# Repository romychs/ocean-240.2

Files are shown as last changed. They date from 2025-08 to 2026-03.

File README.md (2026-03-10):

# Компьютер "Океан-240.2"

Схема и печатная плата новодела компьютера "Океан-240.2". Разработана на основе информации из журнала МПСС и на основе схем, чертежей, правок пользователей форума zx-pk.ru (__L Juriy__, __tnt23__, __ivagor__ и других).

## Основные характеристики

|-|-|
|---|---|
|Разрядность, бит | 8 |
|Быстродействие (рег. — рег.), операций/с| 600 000 |
|Емкость ОЗУ, К байт					 | 128/512 |
|Емкость РПЗУ, К байт					 | 16 |
|__Монитор (серийный цветной):__ | |
| в монохромном режиме |20 строк по 64 символа  |
| в цветном режиме (4 цвета) |графическое поле 256x256|
|Клавиатура | алфавитно-цифровая с контроллером на КМОП ИС | 
|__Интерфейс:__ | |
| последовательный | RS232 | 
| три параллельных программируемых канала| КР580ВВ55 |
| интерфейс печатающего устройства | ИРПР |

__Программное обеспечение:__ монитор с графическими функциями, интерпретатор Бэйсик, квазидисковая операционная система, совместимая с CP/M.

Автор ПЭВМ - __Д. А. Тилинин__

[Исходники](Sources)

[Готовые схемы](Export)

[Прошивки для микросхем ПЗУ](ROMs)

[Файлы для производства печатной платы](Gerbers/Gerber_Ocean-240.2_v1.0.3.zip)

[Темы на форуме zx.pk.ru](https://zx-pk.ru/forums/113-okean-240.html)

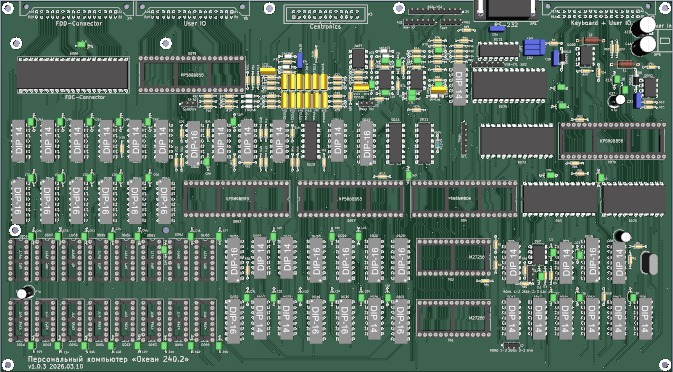
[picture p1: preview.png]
Render


## Изменения
- В версии v1.0.1, Дизассемблированы обе микросхемы ПЗУ, на основе информации из полученных исходников, немного скорректирована схема и печатная плата.
- В версии v1.0.2, Микросхемы DD5 и DD22 на схемах и шелке KiCAD, ошибочно отмечены как ЛИ1. Ошибку заметил при сборке *felix*.
- В версии v1.0.3, Исправлены ошибки предыдущей версии. Документация в папке Export и герберы сгенерированы в KiCAD. Версия EasyEDA больше не будет дорабатываться.

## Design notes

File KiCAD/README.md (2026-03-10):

# Океан-240.2 Персональный компьютер

Схема и печатная плата в [KiCAD](https://www.kicad.org/) v9.0

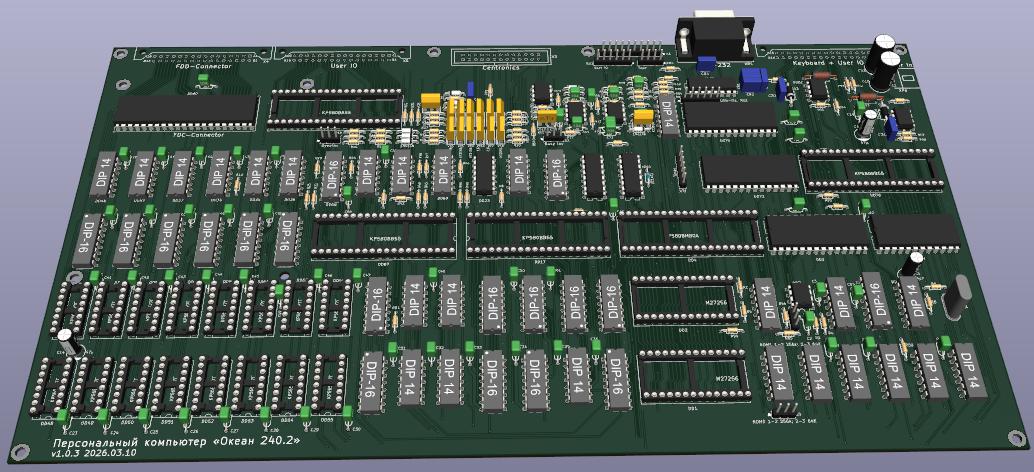
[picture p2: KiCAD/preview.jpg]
Render


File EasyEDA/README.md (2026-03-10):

# Компьютер "Океан-240.2"

Исходные файлы проекта схемы и печатной платы компьютера "Океан-240.2".

Как использовать:

В редакторе [EasyEDA](https://easyeda.com/editor), через "File" > "Open" > "EasyEDA Source", и выберите json файл и откройте его.

At editor, Click the document icon on the topbar, via "Document" > "Open" > "EasyEDA Source", and select json file, then open it at the editor.

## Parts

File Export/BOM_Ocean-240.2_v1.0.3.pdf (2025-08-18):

№ | Позиция | Название | Корпус
| | Конденсаторы
1 | C1 | 4.7μF | Электролит 5x11мм | 1
2 | C2, C3 | 160p | К10-17Б | 2
3 | C4 | 33n | К10-17Б | 1
4 | C5, C8, CR1, CR2, CR3, CR4, CR5 | 0.1μF | К10-17Б | 7
5 | C6 | 100p | К10-17Б | 1
6 | C7 | 470p | К10-17Б | 1
7 | C9, C11 | 10n | К10-17Б | 2
8 | C10 | 68n | К10-17Б | 1
9 | C12 | 2.2n | К10-17Б | 1
10 | C13, C16 | 680μF | Электролит 8x15мм | 2
11 | C14, C17 | 47μF | Электролит 5x11мм | 2
12 | C18, C20 | 1n | К10-17Б | 2
13 | C19, C21 | 1μF | К10-17Б | 2
14 | C23, C24, C25, C26, C27, C28, C29, C30, C31, C32, C33, C34, C35, C36, C37, C38, C39, C40, C41, C42, C43, C44, C45, C46, C47, C48, C50, C51, C53, C54, C55, C56, C57, C58, C60, C61, C62, C63, C64, C65, C66, C67, C68, C69, C70, C71, C72 | 1μF | К10-17Б | 47

Микросхемы
15 | DD1, DD2 | M27256 | DIP-28 | 2
16 | DD3 | КР580ВК28 | DIP-28 | 1
17 | DD4 | КР580ВМ80А | DIP-40 | 1
18 | DD5, DD22 | К1533ЛЛ1 | DIP-14 | 2
19 | DD6, DD65 | К1533ЛИ1 | DIP-14 | 2
20 | DD7 | К170АП3 | DIP-8 | 1
21 | DD8 | К1533ЛН1 | DIP-14 | 1
22 | DD9, DD16 | К1533ЛА3 | DIP-14 | 2
23 | DD10 | К1533ЛЕ1 | DIP-14 | 1
24 | DD11 | К1533ИД4 | DIP-16 | 1
25 | DD12, DD71 | К1533ТЛ2 | DIP-14 | 2
26 | DD13, DD64 | К1533ТМ2 | DIP-14 | 2
27 | DD14, DD34, DD35, DD36, DD37, DD46, DD47 | КР1533ИР16 | DIP-14 | 7
28 | DD15, DD42 | К1533ИЕ7 | DIP-16 | 2
29 | DD17, DD67, DD78, DD79, DD80 | КР580ВВ55 | DIP-40 | 5
30 | DD18, DD19, DD20 | К555ИМ6 | DIP-16 | 3
31 | DA21, DA76, DA77 | TL081 | DIP-8 | 3
32 | DD23 | К1533ЛП5 | DIP-14 | 1
33 | DD24, DD25, DD26, DD27 | К1533ИЕ5 | DIP-14 | 4
34 | DD28, DD29, DD30, DD31, DD32, DD33 | К1533КП12 | DIP-16 | 6
35 | DD38, DD39, DD40, DD41 | КР1533КП13 | DIP-16 | 4
36 | DD43 | К555СП1 | DIP-16 | 1
37 | DD44, DD45 | К1533КП11A | DIP-16 | 2
38 | DD48, DD49, DD50, DD51, DD52, DD53, DD54, DD55, DD56, DD57, DD58, DD59, DD60, DD61, DD62, DD63 | КР565РУ7Г | DIP-16 | 16
39 | DD66 | К556РТ4 | DIP-16 | 1

Коли-чество

40 | DD68, DD69 | К1533ЛН3 | DIP-14 | 2
41 | DD70 | КР580ВИ53 | DIP-24 | 1
42 | DD72 | КР580ВВ51 | DIP-28 | 1
43 | DD73 | MAX232 | DIP-16 | 1
44 | DD75 | КР580ВН59 | DIP-28 | 1
45 | DD82, DD83 | MC34063ABN | DIP-8 | 2

Индуктивности
46 | L1, L2 | 100μH | 2
| | Резисторы
47 | R1, R13, R14, R15, R31, R35, R50, R76, R80 | 5k1 | MF-0.125W | 9
48 | R2, R32, R57, R77, R78, R82, R83, R84, R94, R95, R96, R97 | 10k | MF-0.125W | 12
49 | R3, R4 | 560 | MF-0.125W | 2
50 | R5, R6, R12 | 680 | MF-0.125W | 3
51 | R8, R9, R10, R36, R61, R79, R81 | 1k5 | MF-0.125W | 7
52 | R11, R19, R20, R21 | 1k6 | MF-0.125W | 4
53 | R16, R17, R18 | 3k3 | MF-0.125W | 3
54 | R22, R23, R24, R25 | 910 | MF-0.125W | 4
55 | R26, R28, R29, R30 | 100 | MF-0.125W | 4
56 | R27 | 220 | MF-0.125W | 1
57 | R33, R67 | 20k | MF-0.125W | 2
58 | R34 | 2k | MF-0.125W | 1
59 | R37 | 10 | MF-0.125W | 1
60 | R38, R39, R40, R41, R42, R43, R44, R45, R46, R47, R48, R49, R71, R91, R92, R93 | 1k | MF-0.125W | 16
61 | R51, R52 | 0.33 | MF-0,5W | 2
62 | R53 | 82 | MF-0.125W | 1
63 | R54 | 11k | MF-0.125W | 1
64 | R55 | 1k3 | MF-0.125W | 1
65 | R58, R65, R69, R73 | 30k | MF-0.125W | 4
66 | R62, R63, R72 | 43k | MF-0.125W | 3
67 | R64 | 240k | MF-0.125W | 1
68 | R66 | 82k | MF-0.125W | 1
69 | R68, R70 | 300k | MF-0.125W | 2
70 | R74 | 1M | MF-0.125W | 1
71 | R75 | 51k | MF-0.125W | 1

Перемычки
72 | S1, S2, S3, S4 | Header 3 pin 2.54mm Male | 3

Диоды
73 | VD1, VD2, VD3, VD4, VD5, VD9, VD11, VD12 | 1N4148 | DO-35 | 8
74 | VD6, VD13 | 1N5819 | DO-41 | 2
75 | VD10 | BZX55C4V7 | DO-35 | 1
76 | VT1, VT4, VT5, VT8, VT9, VT11, VT12, VT17 | КТ315Б | КТ-13 | 8
77 | VT2, VT3, VT6, VT7, VT10, VT13, VT16 | КТ361Б | КТ-13 | 7

Разъемы
78 | X2, X4, X5 | DIN-41612 16X2 | 3

79 | X3 | IDC-26 pin male | 1
80 | XM1 | Header 4 pin 2.54mm Male | 1
81 | XP6 | JVC_MINI | 1
82 | XR1 | DB-9 Male | 1
83 | XR2, XT1, XU1 | Header 6 pin 2.54mm Male | 3
86 | XV1 | Header 10 pin 2.54mm Male | 1

Резонаторы
87 | ZQ1 | 12.288MHz | OSC-49U-1 | 1

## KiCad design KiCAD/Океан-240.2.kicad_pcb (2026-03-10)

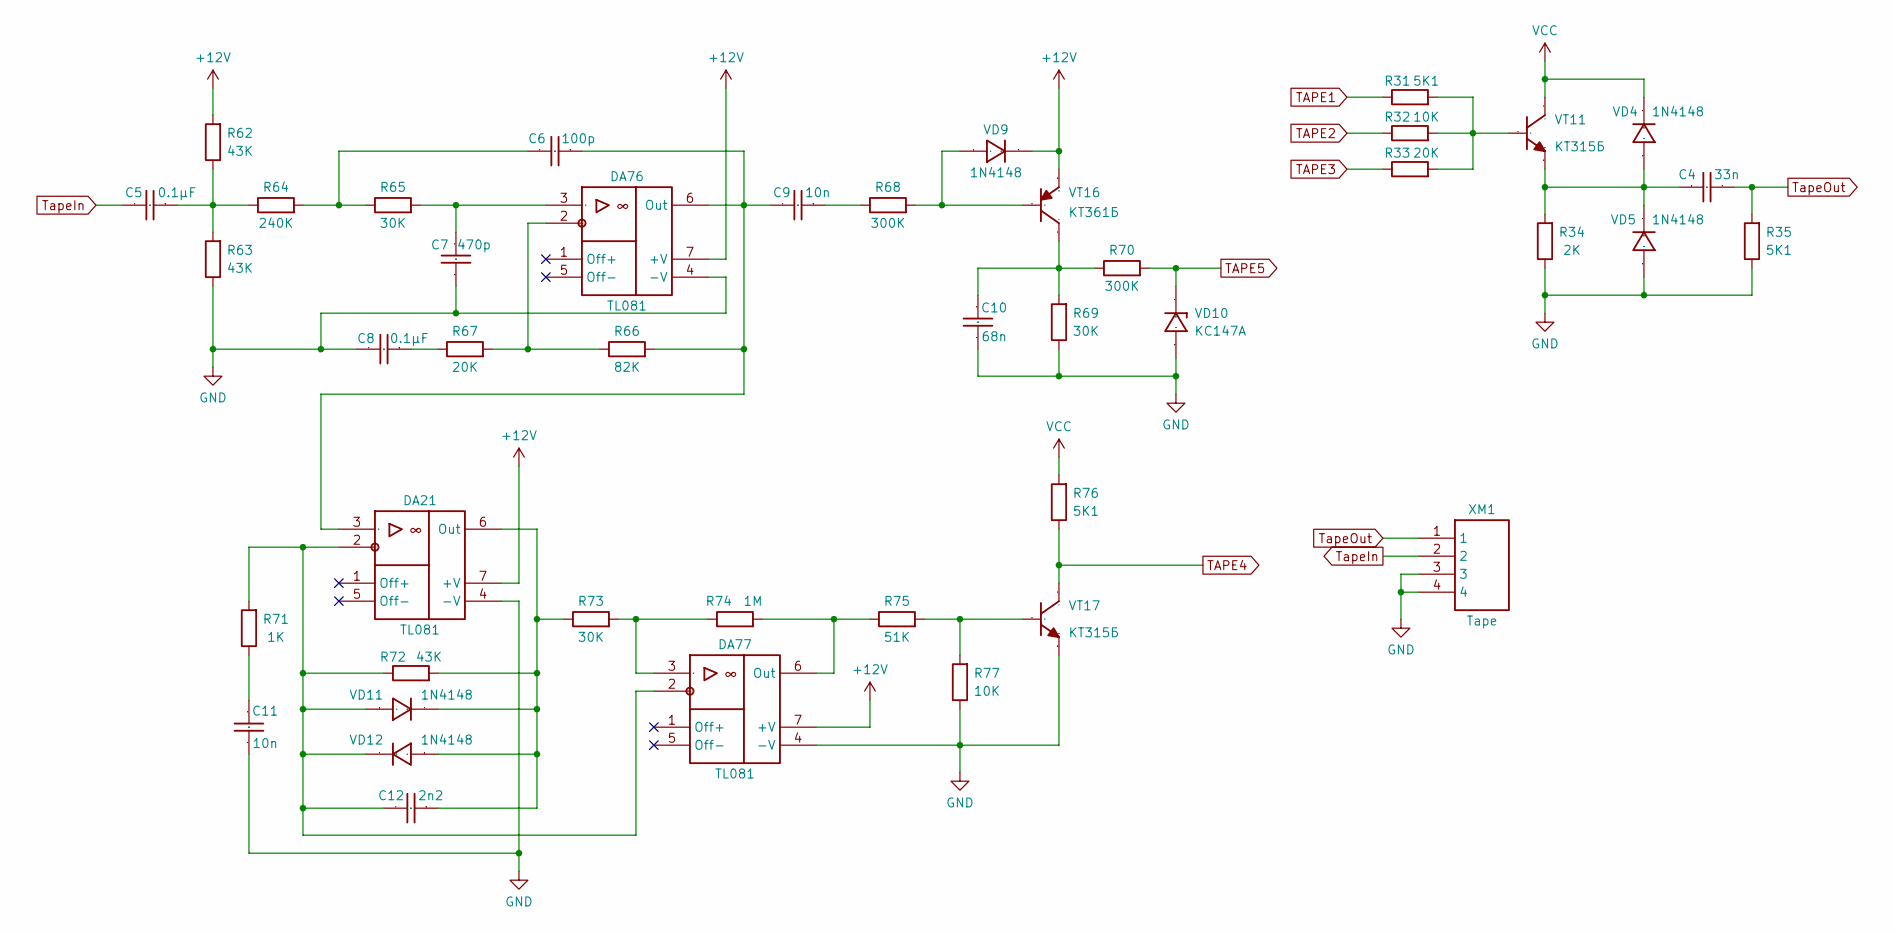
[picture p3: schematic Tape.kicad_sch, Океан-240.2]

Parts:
C4: 33n; CAP-TH_L5.08
C5, C8: 0.1μF; CAP-TH_L7.62
C6: 100p; CAP-TH_L7.62
C7: 470p; CAP-TH_L7.62
C9, C11: 10n; CAP-TH_L7.62
C10: 68n; CAP-TH_L7.62
C12: 2n2; CAP-TH_L7.62
DA21, DA76, DA77: TL081; DIP-8_W7.62mm
R31, R35, R76: 5K1; RES_0.125W_P7.62
R32, R77: 10K; RES_0.125W_P7.62
R33, R67: 20K; RES_0.125W_P7.62
R34: 2K; RES_0.125W_P7.62
R62, R63, R72: 43K; RES_0.125W_P7.62
R64: 240K; RES_0.125W_P7.62
R65, R69, R73: 30K; RES_0.125W_P7.62
R66: 82K; RES_0.125W_P7.62
R68, R70: 300K; RES_0.125W_P7.62
R71: 1K; RES_0.125W_P7.62
R74: 1M; RES_0.125W_P7.62
R75: 51K; RES_0.125W_P7.62
VD4, VD5, VD9, VD11, VD12: 1N4148; DO-35_TH_P7.62
VD10: КС147А; DIODE_TH_7.62
VT11, VT17: КТ315Б; KT315_STD
VT16: КТ361Б; KT315_STD
XM1: Tape; HDR-4P-M-P2.54

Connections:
+12V: DA21.7 (+V), DA76.7 (+V), DA77.7 (+V), R62.2, VD9.2 (K), VT16.1 (E); also elsewhere on the board
GND: C7.1, C8.2, C10.1, C11.1, DA21.4 (-V), DA76.4 (-V), DA77.4 (-V), R34.1, R35.1, R63.1, R69.1, R77.1, VD5.1 (A), VD10.1 (A), VT17.1 (E), XM1.3, XM1.4; also elsewhere on the board
unnamed: C5.1, R62.1, R63.2, R64.1
unnamed: C6.2, R64.2, R65.1
unnamed: C8.1, R67.1
unnamed: C9.1, R68.1
unnamed: C11.2, R71.1
unnamed: C6.1, C9.2, DA21.3 (+), DA76.6 (Out), R66.2
unnamed: C12.2, DA21.2 (-), DA77.2 (-), R71.2, R72.1, VD11.1 (A), VD12.2 (K)
unnamed: C12.1, DA21.6 (Out), R72.2, R73.1, VD11.2 (K), VD12.1 (A)
unnamed: C7.2, DA76.3 (+), R65.2
unnamed: DA76.2 (-), R66.1, R67.2
unnamed: DA77.3 (+), R73.2, R74.1
unnamed: DA77.6 (Out), R74.2, R75.1
unnamed: C4.1, R34.2, VD4.1 (A), VD5.2 (K), VT11.1 (E)
unnamed: R68.2, VD9.1 (A), VT16.3 (B)
unnamed: R31.2, R32.2, R33.2, VT11.3 (B)
unnamed: C10.2, R69.2, R70.1, VT16.2 (C)
unnamed: R75.2, R77.2, VT17.3 (B)
TAPE1: R31.1; also elsewhere on the board
TAPE2: R32.1; also elsewhere on the board
TAPE3: R33.1; also elsewhere on the board
TAPE4: R76.1, VT17.2 (C); also elsewhere on the board
TAPE5: R70.2, VD10.2 (K); also elsewhere on the board
TapeIn: C5.2, XM1.2
TapeOut: C4.2, R35.2, XM1.1
VCC: R76.2, VD4.2 (K), VT11.2 (C); also elsewhere on the board

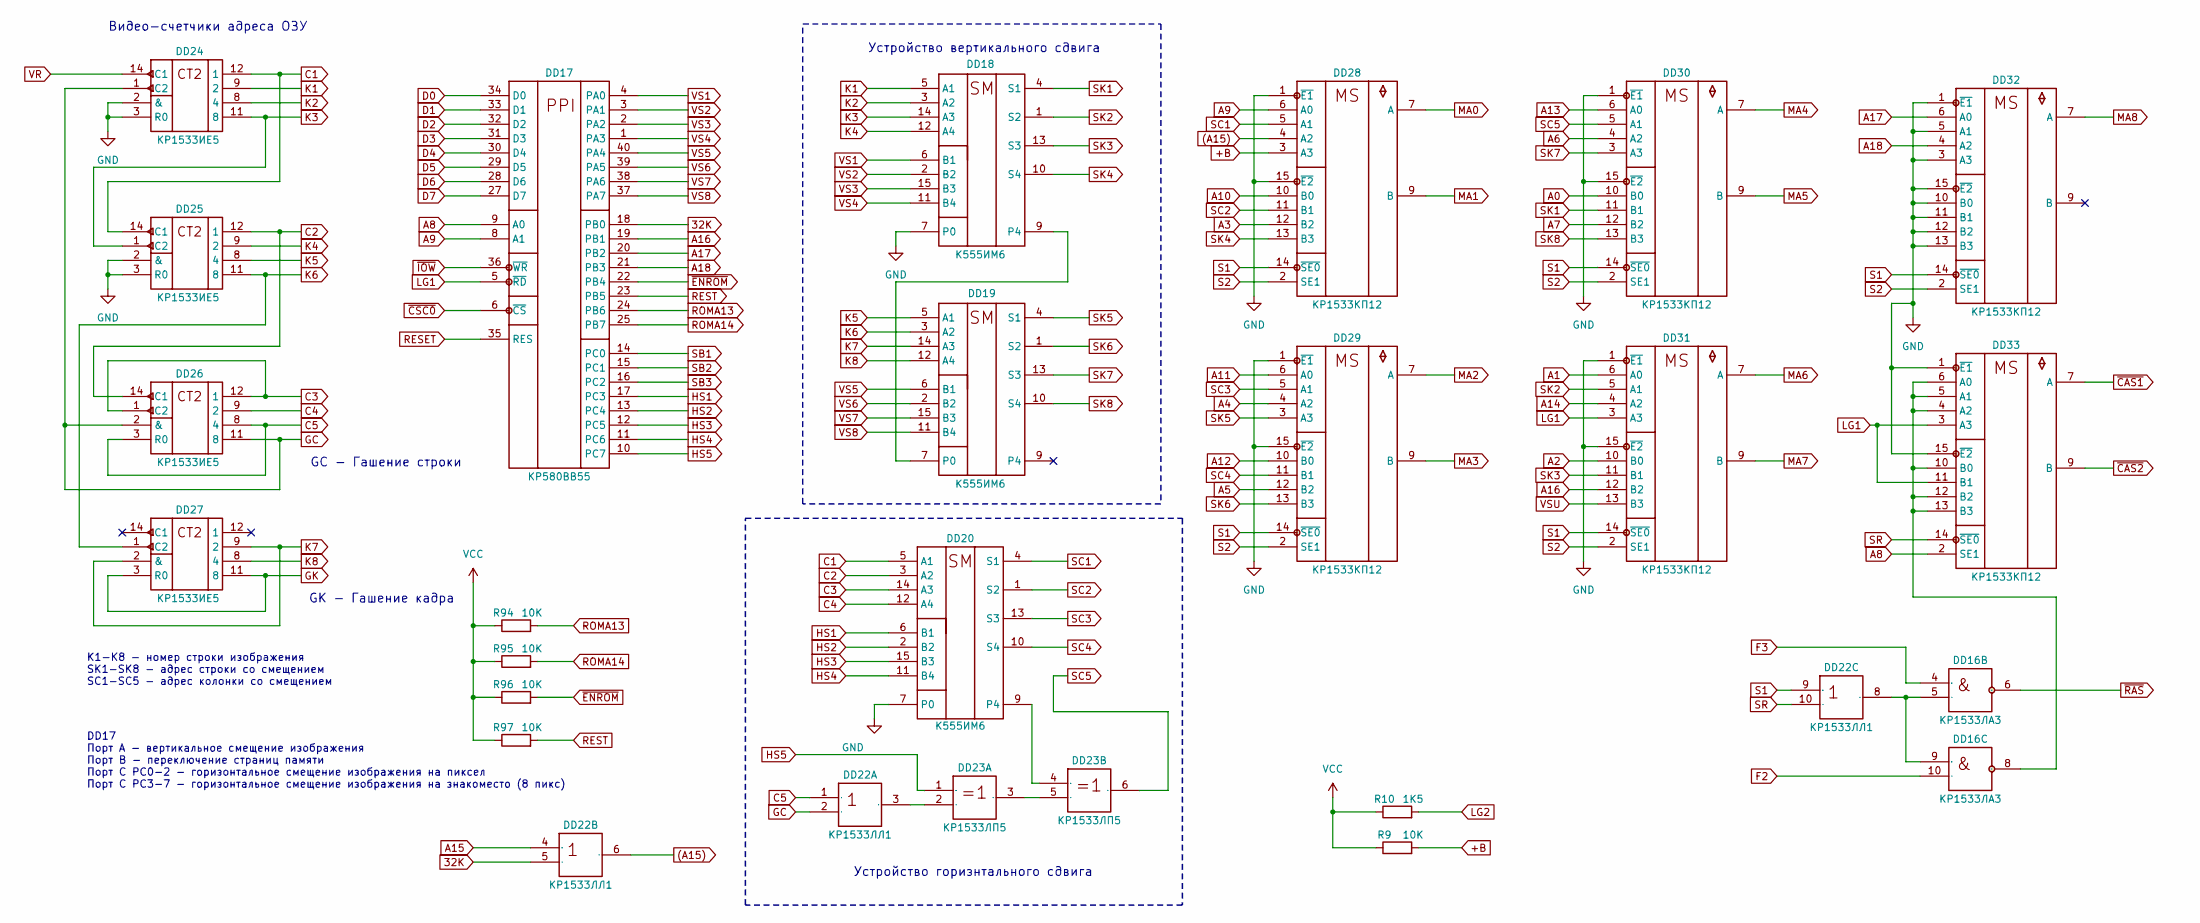
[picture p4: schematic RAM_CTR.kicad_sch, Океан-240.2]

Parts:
DD16: КР1533ЛА3; DIP-14_W7.62mm
DD17: КР580ВВ55; DIP-40_W15.24mm_Socket
DD18, DD19, DD20: К555ИМ6; DIP-16_W7.62mm
DD22: КР1533ЛЛ1; DIP-14_W7.62mm
DD23: КР1533ЛП5; DIP-14_W7.62mm
DD24, DD25, DD26, DD27: КР1533ИЕ5; DIP-14_W7.62mm
DD28, DD29, DD30, DD31, DD32, DD33: КР1533КП12; DIP-16_W7.62mm
R9, R94, R95, R96, R97: 10K; RES_0.125W_P7.62
R10: 1K5; RES_0.125W_P7.62

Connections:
32K: DD17.18 (PB0), DD22.5 (2)
(A15): DD22.6 (3), DD28.4 (A2)
+B: DD28.3 (A3), R9.2
A0: DD30.10 (B0); also elsewhere on the board
A1: DD31.6 (A0); also elsewhere on the board
A2: DD31.10 (B0); also elsewhere on the board
A3: DD28.12 (B2); also elsewhere on the board
A4: DD29.4 (A2); also elsewhere on the board
A5: DD29.12 (B2); also elsewhere on the board
A6: DD30.4 (A2); also elsewhere on the board
A7: DD30.12 (B2); also elsewhere on the board
A8: DD17.9 (A0), DD33.2 (SE1); also elsewhere on the board
A9: DD17.8 (A1), DD28.6 (A0); also elsewhere on the board
A10: DD28.10 (B0); also elsewhere on the board
A11: DD29.6 (A0); also elsewhere on the board
A12: DD29.10 (B0); also elsewhere on the board
A13: DD30.6 (A0); also elsewhere on the board
A14: DD31.4 (A2); also elsewhere on the board
A15: DD22.4 (1); also elsewhere on the board
A16: DD17.19 (PB1), DD31.12 (B2)
A17: DD17.20 (PB2), DD32.6 (A0)
A18: DD17.21 (PB3), DD32.4 (A2)
C1: DD20.5 (A1), DD24.12 (1), DD25.14 (C1)
C2: DD20.3 (A2), DD25.12 (1), DD26.14 (C1)
C3: DD20.14 (A3), DD26.1 (C2), DD26.12 (1); also elsewhere on the board
C4: DD20.12 (A4), DD26.9 (2); also elsewhere on the board
C5: DD22.1, DD26.3 (R0), DD26.8 (4)
D0: DD17.34 (D0); also elsewhere on the board
D1: DD17.33 (D1); also elsewhere on the board
D2: DD17.32 (D2); also elsewhere on the board
D3: DD17.31 (D3); also elsewhere on the board
D4: DD17.30 (D4); also elsewhere on the board
D5: DD17.29 (D5); also elsewhere on the board
D6: DD17.28 (D6); also elsewhere on the board
D7: DD17.27 (D7); also elsewhere on the board
F2: DD16.10 (2); also elsewhere on the board
F3: DD16.4 (1); also elsewhere on the board
GC: DD22.2, DD24.1 (C2), DD26.2 (&), DD26.11 (8); also elsewhere on the board
GK: DD27.3 (R0), DD27.11 (8); also elsewhere on the board
GND: DD17.7 (GND), DD18.7 (P0), DD18.8 (GND), DD19.8 (GND), DD20.7 (P0), DD20.8 (GND), DD22.7 (GND), DD23.7 (GND), DD24.2 (&), DD24.3 (R0), DD24.10 (GND), DD25.2 (&), DD25.3 (R0), DD25.10 (GND), DD26.10 (GND), DD27.10 (GND), DD28.1 (~E1), DD28.8 (GND), DD28.15 (~E2), DD29.1 (~E1), DD29.8 (GND), DD29.15 (~E2), DD30.1 (~E1), DD30.8 (GND), DD30.15 (~E2), DD31.1 (~E1), DD31.8 (GND), DD31.15 (~E2), DD32.1 (~E1), DD32.3 (A3), DD32.5 (A1), DD32.8 (GND), DD32.10 (B0), DD32.11 (B1), DD32.12 (B2), DD32.13 (B3), DD32.15 (~E2), DD33.1 (~E1), DD33.8 (GND), DD33.15 (~E2); also elsewhere on the board
HS1: DD17.17 (PC3), DD20.6 (B1)
HS2: DD17.13 (PC4), DD20.2 (B2)
HS3: DD17.12 (PC5), DD20.15 (B3)
HS4: DD17.11 (PC6), DD20.11 (B4)
HS5: DD17.10 (PC7), DD23.1
K1: DD18.5 (A1), DD24.9 (2)
K2: DD18.3 (A2), DD24.8 (4)
K3: DD18.14 (A3), DD24.11 (8), DD25.1 (C2)
K4: DD18.12 (A4), DD25.9 (2)
K5: DD19.5 (A1), DD25.8 (4); also elsewhere on the board
K6: DD19.3 (A2), DD25.11 (8), DD27.1 (C2); also elsewhere on the board
K7: DD19.14 (A3), DD27.2 (&), DD27.9 (2)
K8: DD19.12 (A4), DD27.8 (4)
LG1: DD17.5 (~RD), DD31.3 (A3), DD33.3 (A3), DD33.11 (B1); also elsewhere on the board
LG2: R10.2; also elsewhere on the board
MA0: DD28.7 (A); also elsewhere on the board
MA1: DD28.9 (B); also elsewhere on the board
MA2: DD29.7 (A); also elsewhere on the board
MA3: DD29.9 (B); also elsewhere on the board
MA4: DD30.7 (A); also elsewhere on the board
MA5: DD30.9 (B); also elsewhere on the board
MA6: DD31.7 (A); also elsewhere on the board
MA7: DD31.9 (B); also elsewhere on the board
MA8: DD32.7 (A); also elsewhere on the board
unnamed: DD16.5 (2), DD16.9 (1), DD22.8 (3)
unnamed: DD16.8 (3), DD33.4 (A2), DD33.5 (A1), DD33.6 (A0), DD33.10 (B0), DD33.12 (B2), DD33.13 (B3)
unnamed: DD18.9 (P4), DD19.7 (P0)
unnamed: DD20.9 (P4), DD23.4 (1)
unnamed: DD22.3, DD23.2
unnamed: DD23.3, DD23.5 (2)
RESET: DD17.35 (RES); also elsewhere on the board
REST: DD17.23 (PB5), R97.2; also elsewhere on the board
ROMA13: DD17.24 (PB6), R94.2; also elsewhere on the board
ROMA14: DD17.25 (PB7), R95.2; also elsewhere on the board
S1: DD22.9 (1), DD28.14 (~SE0), DD29.14 (~SE0), DD30.14 (~SE0), DD31.14 (~SE0), DD32.14 (~SE0); also elsewhere on the board
S2: DD28.2 (SE1), DD29.2 (SE1), DD30.2 (SE1), DD31.2 (SE1), DD32.2 (SE1); also elsewhere on the board
SB1: DD17.14 (PC0); also elsewhere on the board
SB2: DD17.15 (PC1); also elsewhere on the board
SB3: DD17.16 (PC2); also elsewhere on the board
SC1: DD20.4 (S1), DD28.5 (A1)
SC2: DD20.1 (S2), DD28.11 (B1)
SC3: DD20.13 (S3), DD29.5 (A1)
SC4: DD20.10 (S4), DD29.11 (B1)
SC5: DD23.6 (3), DD30.5 (A1)
SK1: DD18.4 (S1), DD30.11 (B1)
SK2: DD18.1 (S2), DD31.5 (A1)
SK3: DD18.13 (S3), DD31.11 (B1)
SK4: DD18.10 (S4), DD28.13 (B3)
SK5: DD19.4 (S1), DD29.3 (A3)
SK6: DD19.1 (S2), DD29.13 (B3)
SK7: DD19.13 (S3), DD30.3 (A3)
SK8: DD19.10 (S4), DD30.13 (B3)
SR: DD22.10 (2), DD33.14 (~SE0); also elsewhere on the board
VCC: DD17.26 (VCC), DD18.16 (VCC), DD19.16 (VCC), DD20.16 (VCC), DD22.14 (VCC), DD23.14 (VCC), DD24.5 (VCC), DD25.5 (VCC), DD26.5 (VCC), DD27.5 (VCC), DD28.16 (VCC), DD29.16 (VCC), DD30.16 (VCC), DD31.16 (VCC), DD32.16 (VCC), DD33.16 (VCC), R9.1, R10.1, R94.1, R95.1, R96.1, R97.1; also elsewhere on the board
VR: DD24.14 (C1); also elsewhere on the board
VS1: DD17.4 (PA0), DD18.6 (B1)
VS2: DD17.3 (PA1), DD18.2 (B2)
VS3: DD17.2 (PA2), DD18.15 (B3)
VS4: DD17.1 (PA3), DD18.11 (B4)
VS5: DD17.40 (PA4), DD19.6 (B1)
VS6: DD17.39 (PA5), DD19.2 (B2)
VS7: DD17.38 (PA6), DD19.15 (B3)
VS8: DD17.37 (PA7), DD19.11 (B4)
VSU: DD31.13 (B3); also elsewhere on the board
~CAS1: DD33.7 (A); also elsewhere on the board
~CAS2: DD33.9 (B); also elsewhere on the board
~CSC0: DD17.6 (~CS); also elsewhere on the board
~ENROM: DD17.22 (PB4), R96.2; also elsewhere on the board
~IOW: DD17.36 (~WR); also elsewhere on the board
~RAS: DD16.6 (3); also elsewhere on the board

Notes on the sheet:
Устройство горизнтального сдвига
GK - Гашение кадра
K1-K8 - номер строки изображения SK1-SK8 - адрес строки со смещением SC1-SC5 - адрес колонки со смещением
Видео-счетчики адреса ОЗУ
GC - Гашение строки
Устройство вертикального сдвига
DD17 Порт А - вертикальное смещение изображения Порт B - переключение страниц памяти Порт C PC0-2 - горизонтальное смещение изображения на пиксел Порт C PC3-7 - горизонтальное смещение изображения на знакоместо (8 пикс)

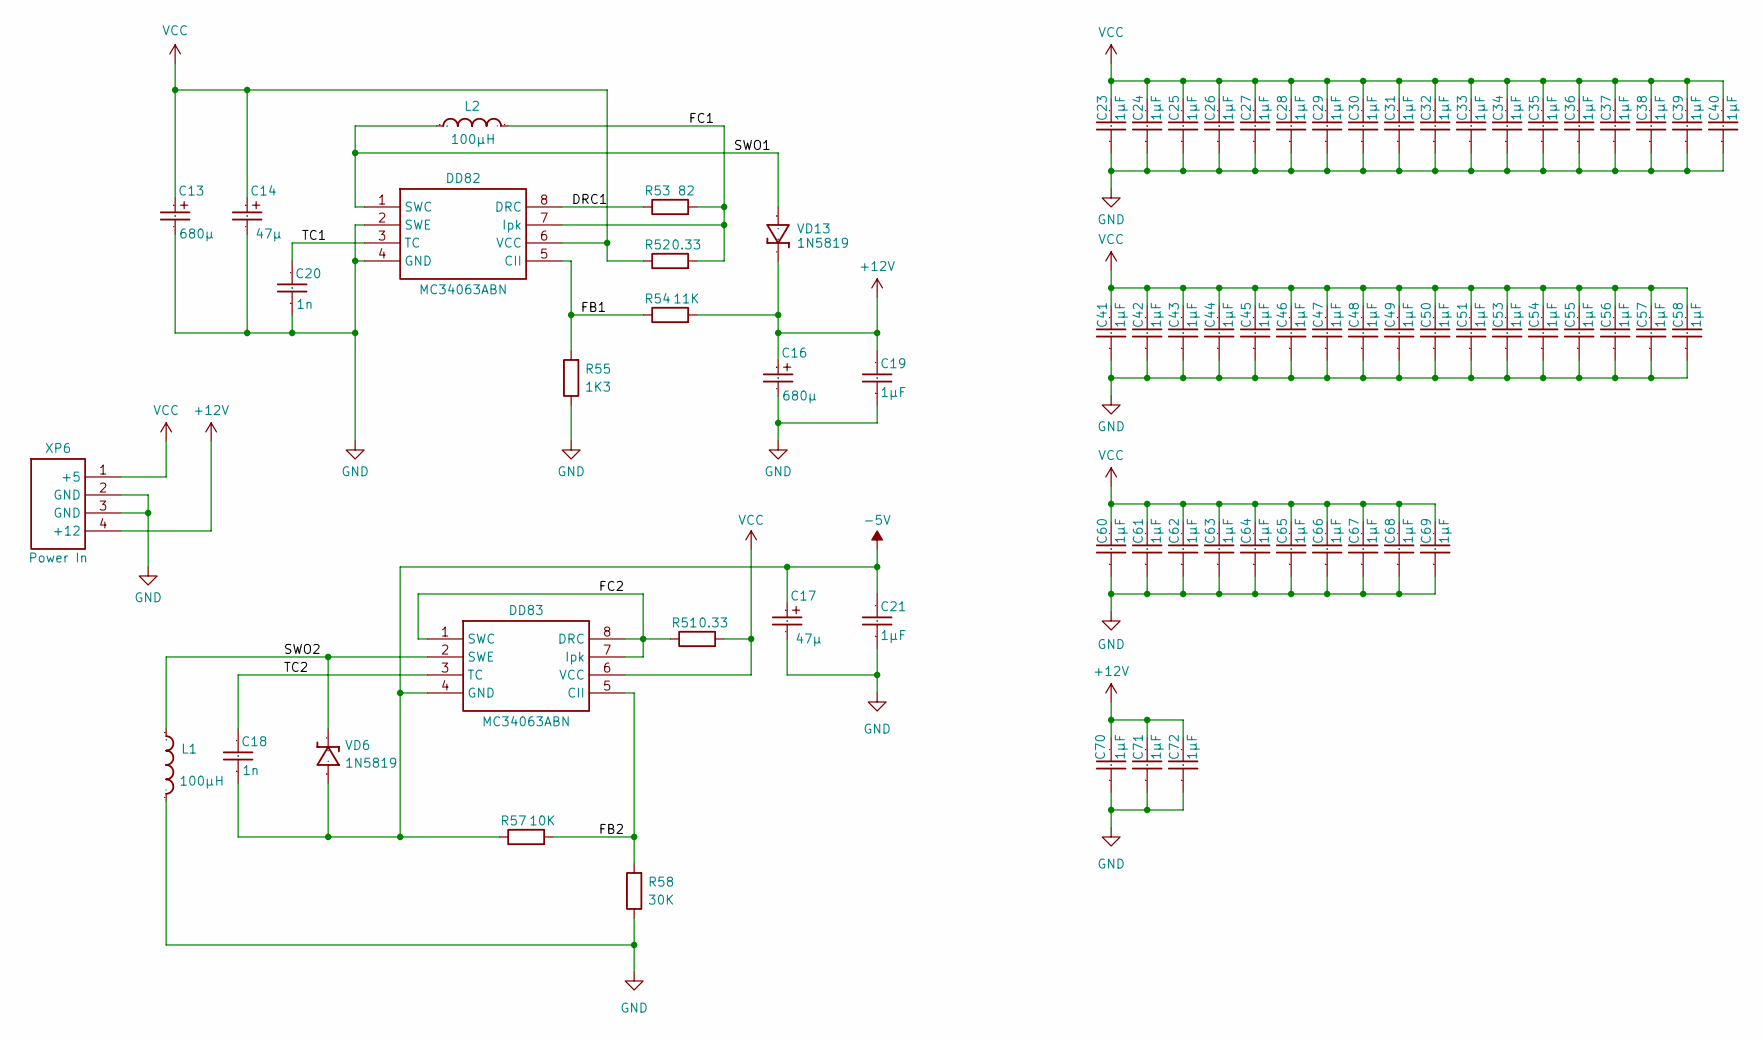
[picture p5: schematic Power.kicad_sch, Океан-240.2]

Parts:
C13, C16: 680μ; CAP_P-TH-8x15-P3.556
C14, C17: 47μ; CAP_P-TH-5x11-P2.54
C18: 1n; CAP-TH_L7.62
C19, C23, C24, C25, C26, C27, C28, C29, C30, C31, C32, C33, C34, C35, C36, C37, C38, C39, C40, C41, C42, C43, C44, C45, C46, C47, C48, C49, C50, C51, C53, C54, C55, C56, C57, C58, C60, C61, C62, C63, C64, C65, C66, C67, C68, C69, C70, C71, C72: 1μF; CAP-TH_L7.62
C20: 1n; CAP-TH_L5.08
C21: 1μF; CAP-TH_L5.08
DD82, DD83: MC34063ABN; DIP-8_W7.62mm
L1, L2: 100μH; L_Axial_L7.0mm_D3.3mm_P12.70mm_Horizontal_Fastron_MICC
R51, R52: 0.33; RES_0.125W_P7.62
R53: 82; RES_0.125W_P7.62
R54: 11K; RES_0.125W_P7.62
R55: 1K3; RES_0.125W_P7.62
R57: 10K; RES_0.125W_P7.62
R58: 30K; RES_0.125W_P7.62
VD6, VD13: 1N5819; DO-41_STD_P10.16
XP6: Power In; JVC_MINI-TH-4P

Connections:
+12V: C16.1, C19.2, C70.2, C71.2, C72.2, R54.2, VD13.2 (K), XP6.4 (+12); also elsewhere on the board
-5V: C17.1, C18.1, C21.2, DD83.4 (GND), R57.1, VD6.1 (A); also elsewhere on the board
/Океан-240.2 - Источники питания/DRC1: DD82.8 (DRC), R53.1
/Океан-240.2 - Источники питания/FB1: DD82.5 (CII), R54.1, R55.2
/Океан-240.2 - Источники питания/FB2: DD83.5 (CII), R57.2, R58.2
/Океан-240.2 - Источники питания/FC1: DD82.7 (Ipk), L2.2, R52.2, R53.2
/Океан-240.2 - Источники питания/FC2: DD83.1 (SWC), DD83.7 (Ipk), DD83.8 (DRC), R51.1
/Океан-240.2 - Источники питания/SWO1: DD82.1 (SWC), L2.1, VD13.1 (A)
/Океан-240.2 - Источники питания/SWO2: DD83.2 (SWE), L1.1, VD6.2 (K)
/Океан-240.2 - Источники питания/TC1: C20.2, DD82.3 (TC)
/Океан-240.2 - Источники питания/TC2: C18.2, DD83.3 (TC)
GND: C13.2, C14.2, C16.2, C17.2, C19.1, C20.1, C21.1, C23.1, C24.1, C25.1, C26.1, C27.1, C28.1, C29.1, C30.1, C31.1, C32.1, C33.1, C34.1, C35.1, C36.1, C37.1, C38.1, C39.1, C40.1, C41.1, C42.1, C43.1, C44.1, C45.1, C46.1, C47.1, C48.1, C49.1, C50.1, C51.1, C53.1, C54.1, C55.1, C56.1, C57.1, C58.1, C60.1, C61.1, C62.1, C63.1, C64.1, C65.1, C66.1, C67.1, C68.1, C69.1, C70.1, C71.1, C72.1, DD82.2 (SWE), DD82.4 (GND), L1.2, R55.1, R58.1, XP6.2 (GND), XP6.3 (GND); also elsewhere on the board
VCC: C13.1, C14.1, C23.2, C24.2, C25.2, C26.2, C27.2, C28.2, C29.2, C30.2, C31.2, C32.2, C33.2, C34.2, C35.2, C36.2, C37.2, C38.2, C39.2, C40.2, C41.2, C42.2, C43.2, C44.2, C45.2, C46.2, C47.2, C48.2, C49.2, C50.2, C51.2, C53.2, C54.2, C55.2, C56.2, C57.2, C58.2, C60.2, C61.2, C62.2, C63.2, C64.2, C65.2, C66.2, C67.2, C68.2, C69.2, DD82.6 (VCC), DD83.6 (VCC), R51.2, R52.1, XP6.1 (+5); also elsewhere on the board

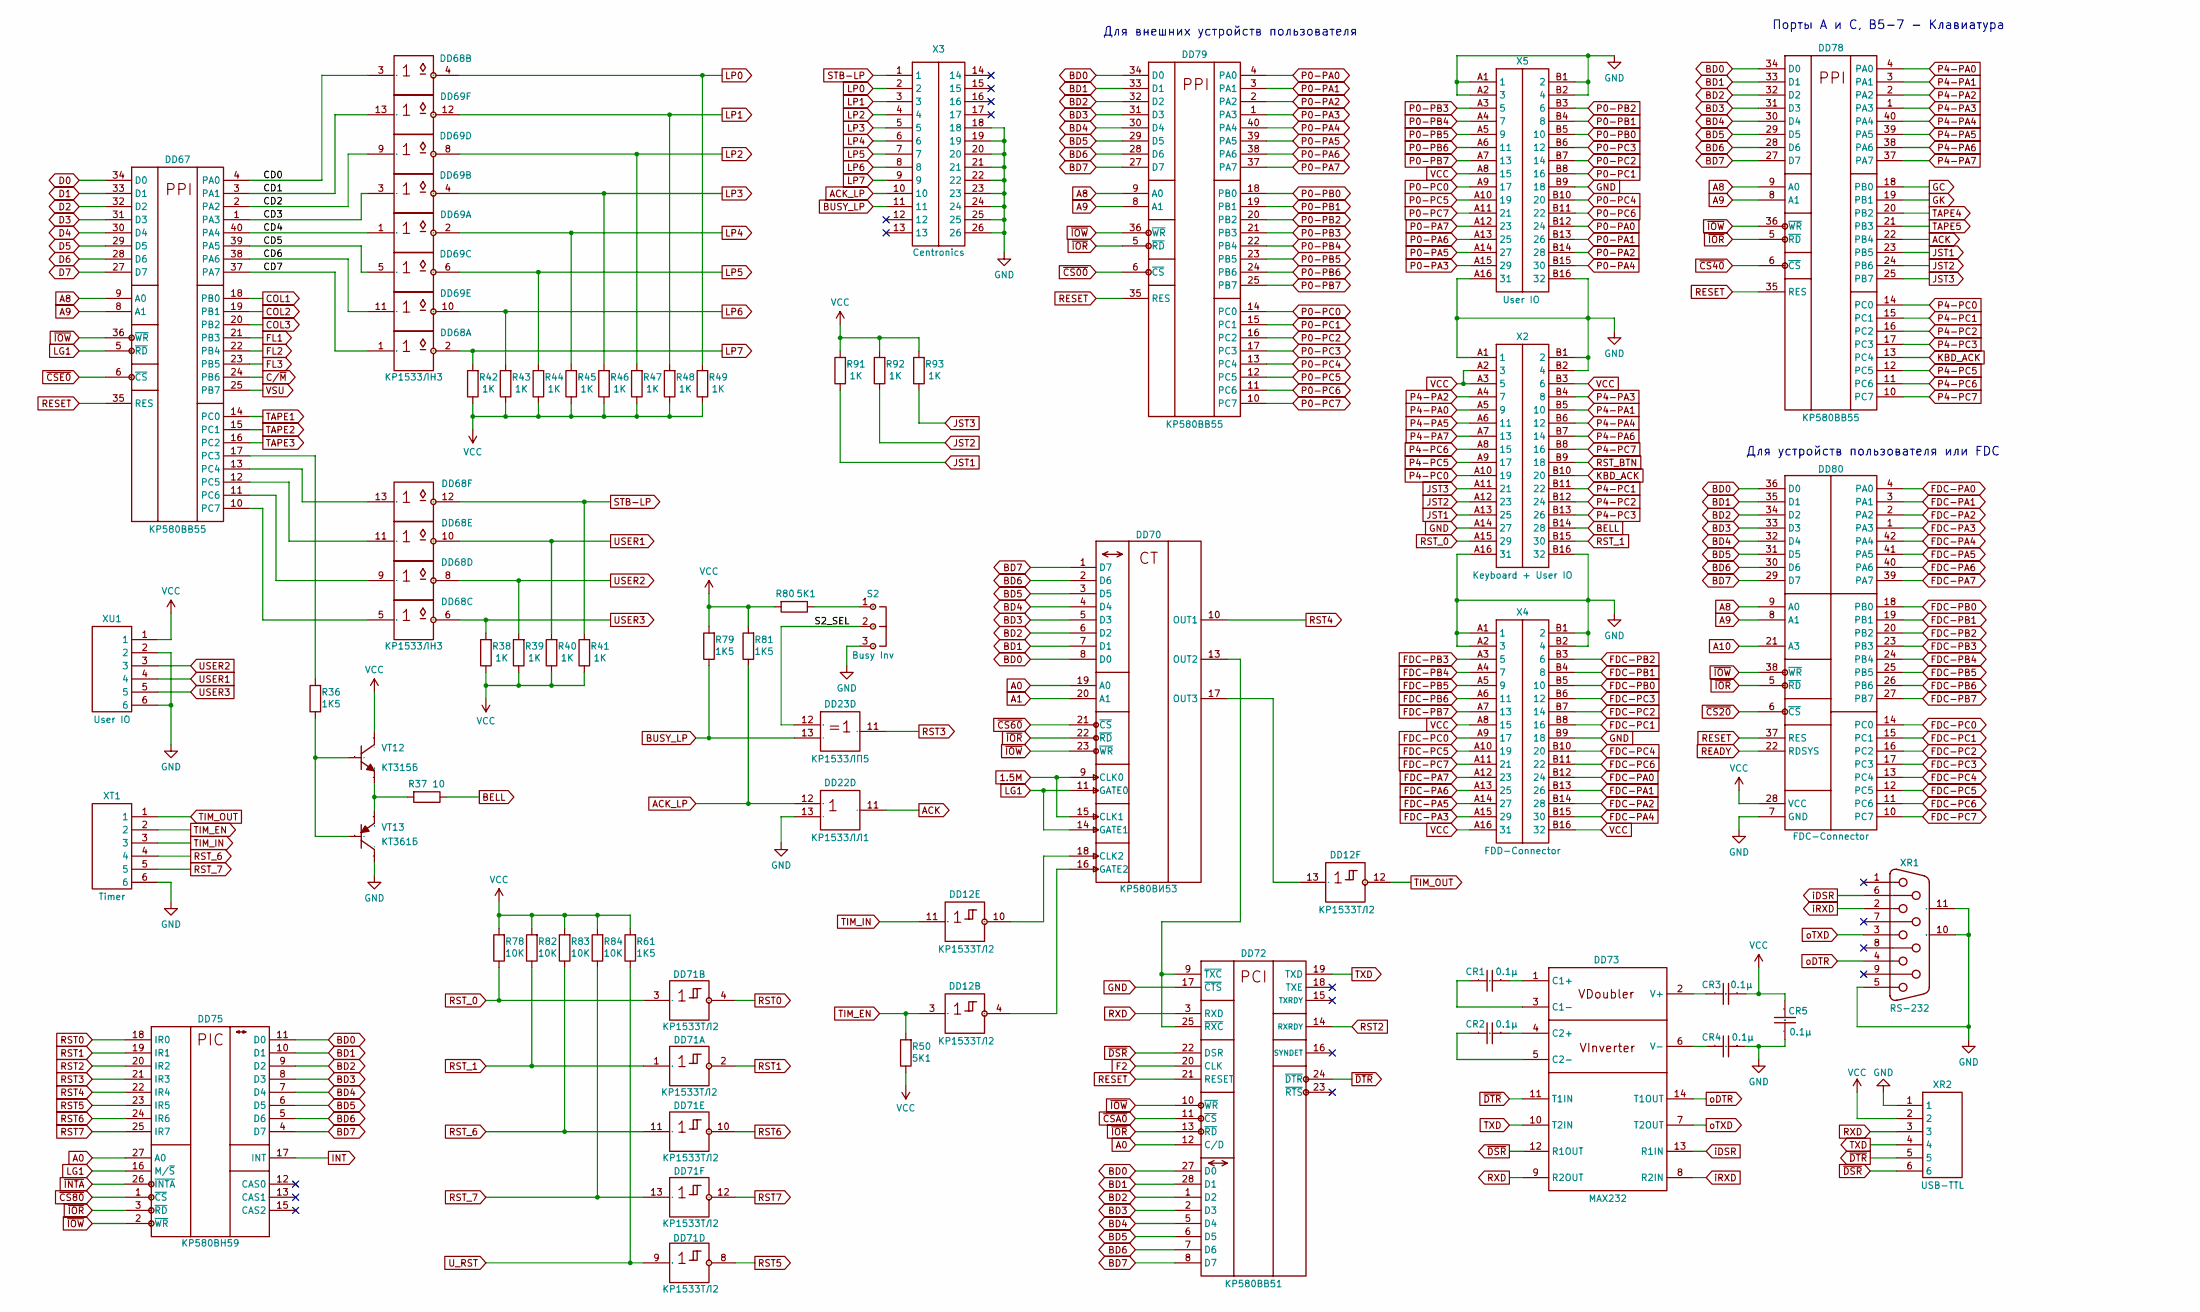
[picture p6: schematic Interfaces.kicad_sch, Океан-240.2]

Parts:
CR1, CR2, CR3, CR4, CR5: 0.1μ; CAP-TH_L5.08
DD12, DD71: КР1533ТЛ2; DIP-14_W7.62mm
DD22: КР1533ЛЛ1; DIP-14_W7.62mm
DD23: КР1533ЛП5; DIP-14_W7.62mm
DD67, DD78, DD79: КР580ВВ55; DIP-40_W15.24mm_Socket
DD68, DD69: КР1533ЛН3; DIP-14_W7.62mm
DD70: КР580ВИ53; DIP-24_W15.24mm
DD72: КР580ВВ51; DIP-28_W15.24mm
DD73: MAX232; DIP-16_W7.62mm
DD75: КР580ВН59; DIP-28_W15.24mm
DD80: FDC-Connector; DIP-42_W15.24mm_Socket
R36, R61, R79, R81: 1K5; RES_0.125W_P7.62
R37: 10; RES_0.125W_P7.62
R38, R39, R40, R41, R42, R43, R44, R45, R46, R47, R48, R49, R91, R92, R93: 1K; RES_0.125W_P7.62
R50, R80: 5K1; RES_0.125W_P7.62
R78, R82, R83, R84: 10K; RES_0.125W_P7.62
S2: Busy Inv; HDR-3P-M-P2.54
VT12: КТ315Б; KT315_STD
VT13: КТ361Б; KT315_STD
X2: Keyboard + User IO; DIN_41612_16X2P_F
X3: Centronics; IDC-TH_26P-P2.54M
X4: FDD-Connector; DIN_41612_16X2P_F
X5: User IO; DIN_41612_16X2P_F
XR1: RS-232; DB9-TH
XR2: USB-TTL; HDR-6P-M-P2.54
XT1: Timer; HDR-6P-M-P2.54
XU1: User IO; HDR-6P-M-P2.54

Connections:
1.5M: DD70.9 (CLK0), DD70.15 (CLK1); also elsewhere on the board
/Океан-240.2 - Интерфейсы/CD0: DD67.4 (PA0), DD68.3 (1)
/Океан-240.2 - Интерфейсы/CD1: DD67.3 (PA1), DD69.13 (1)
/Океан-240.2 - Интерфейсы/CD2: DD67.2 (PA2), DD69.9 (1)
/Океан-240.2 - Интерфейсы/CD3: DD67.1 (PA3), DD69.3 (1)
/Океан-240.2 - Интерфейсы/CD4: DD67.40 (PA4), DD69.1
/Океан-240.2 - Интерфейсы/CD5: DD67.39 (PA5), DD69.5 (1)
/Океан-240.2 - Интерфейсы/CD6: DD67.38 (PA6), DD69.11 (1)
/Океан-240.2 - Интерфейсы/CD7: DD67.37 (PA7), DD68.1
/Океан-240.2 - Интерфейсы/S2_SEL: DD23.12 (1), S2.2
A0: DD70.19 (A0), DD72.12 (C/D), DD75.27 (A0); also elsewhere on the board
A1: DD70.20 (A1); also elsewhere on the board
A8: DD67.9 (A0), DD78.9 (A0), DD79.9 (A0), DD80.9 (A0); also elsewhere on the board
A9: DD67.8 (A1), DD78.8 (A1), DD79.8 (A1), DD80.8 (A1); also elsewhere on the board
A10: DD80.21 (A3); also elsewhere on the board
ACK: DD22.11 (3), DD78.22 (PB4)
ACK_LP: DD22.12 (1), R81.1, X3.10
BD0: DD70.8 (D0), DD72.27 (D0), DD75.11 (D0), DD78.34 (D0), DD79.34 (D0), DD80.36 (D0); also elsewhere on the board
BD1: DD70.7 (D1), DD72.28 (D1), DD75.10 (D1), DD78.33 (D1), DD79.33 (D1), DD80.35 (D1); also elsewhere on the board
BD2: DD70.6 (D2), DD72.1 (D2), DD75.9 (D2), DD78.32 (D2), DD79.32 (D2), DD80.34 (D2); also elsewhere on the board
BD3: DD70.5 (D3), DD72.2 (D3), DD75.8 (D3), DD78.31 (D3), DD79.31 (D3), DD80.33 (D3); also elsewhere on the board
BD4: DD70.4 (D4), DD72.5 (D4), DD75.7 (D4), DD78.30 (D4), DD79.30 (D4), DD80.32 (D4); also elsewhere on the board
BD5: DD70.3 (D5), DD72.6 (D5), DD75.6 (D5), DD78.29 (D5), DD79.29 (D5), DD80.31 (D5); also elsewhere on the board
BD6: DD70.2 (D6), DD72.7 (D6), DD75.5 (D6), DD78.28 (D6), DD79.28 (D6), DD80.30 (D6); also elsewhere on the board
BD7: DD70.1 (D7), DD72.8 (D7), DD75.4 (D7), DD78.27 (D7), DD79.27 (D7), DD80.29 (D7); also elsewhere on the board
BELL: R37.1, X2.B14 (28)
BUSY_LP: DD23.13 (2), R79.1, X3.11
COL1: DD67.18 (PB0); also elsewhere on the board
COL2: DD67.19 (PB1); also elsewhere on the board
COL3: DD67.20 (PB2); also elsewhere on the board
C/~M: DD67.24 (PB6); also elsewhere on the board
D0: DD67.34 (D0); also elsewhere on the board
D1: DD67.33 (D1); also elsewhere on the board
D2: DD67.32 (D2); also elsewhere on the board
D3: DD67.31 (D3); also elsewhere on the board
D4: DD67.30 (D4); also elsewhere on the board
D5: DD67.29 (D5); also elsewhere on the board
D6: DD67.28 (D6); also elsewhere on the board
D7: DD67.27 (D7); also elsewhere on the board
F2: DD72.20 (CLK); also elsewhere on the board
FDC-PA0: DD80.4 (PA0), X4.B12 (24)
FDC-PA1: DD80.3 (PA1), X4.B13 (26)
FDC-PA2: DD80.2 (PA2), X4.B14 (28)
FDC-PA3: DD80.1 (PA3), X4.A15 (29)
FDC-PA4: DD80.42 (PA4), X4.B15 (30)
FDC-PA5: DD80.41 (PA5), X4.A14 (27)
FDC-PA6: DD80.40 (PA6), X4.A13 (25)
FDC-PA7: DD80.39 (PA7), X4.A12 (23)
FDC-PB0: DD80.18 (PB0), X4.B5 (10)
FDC-PB1: DD80.19 (PB1), X4.B4 (8)
FDC-PB2: DD80.20 (PB2), X4.B3 (6)
FDC-PB3: DD80.23 (PB3), X4.A3 (5)
FDC-PB4: DD80.24 (PB4), X4.A4 (7)
FDC-PB5: DD80.25 (PB5), X4.A5 (9)
FDC-PB6: DD80.26 (PB6), X4.A6 (11)
FDC-PB7: DD80.27 (PB7), X4.A7 (13)
FDC-PC0: DD80.14 (PC0), X4.A9 (17)
FDC-PC1: DD80.15 (PC1), X4.B8 (16)
FDC-PC2: DD80.16 (PC2), X4.B7 (14)
FDC-PC3: DD80.17 (PC3), X4.B6 (12)
FDC-PC4: DD80.13 (PC4), X4.B10 (20)
FDC-PC5: DD80.12 (PC5), X4.A10 (19)
FDC-PC6: DD80.11 (PC6), X4.B11 (22)
FDC-PC7: DD80.10 (PC7), X4.A11 (21)
FL1: DD67.21 (PB3); also elsewhere on the board
FL2: DD67.22 (PB4); also elsewhere on the board
FL3: DD67.23 (PB5); also elsewhere on the board
GC: DD78.18 (PB0); also elsewhere on the board
GK: DD78.19 (PB1); also elsewhere on the board
GND: CR4.1, CR5.2, DD22.13 (2), DD67.7 (GND), DD68.7 (GND), DD69.7 (GND), DD70.12 (GND), DD71.7 (GND), DD72.4 (GND), DD72.17 (~CTS), DD73.15 (GND), DD75.14 (GND), DD78.7 (GND), DD79.7 (GND), DD80.7 (GND), S2.3, VT13.2 (C), X2.A1 (1), X2.A14 (27), X2.A16 (31), X2.B1 (2), X2.B2 (4), X2.B16 (32), X3.18, X3.19, X3.20, X3.21, X3.22, X3.23, X3.24, X3.25, X3.26, X4.A1 (1), X4.A2 (3), X4.B1 (2), X4.B2 (4), X4.B9 (18), X5.A1 (1), X5.A2 (3), X5.A16 (31), X5.B1 (2), X5.B2 (4), X5.B9 (18), X5.B16 (32), XR1.5, XR1.10 (MH1), XR1.11 (MH2), XR2.1, XT1.6, XU1.2, XU1.6; also elsewhere on the board
INT: DD75.17 (INT); also elsewhere on the board
JST1: DD78.23 (PB5), R91.1, X2.A13 (25)
JST2: DD78.24 (PB6), R92.1, X2.A12 (23)
JST3: DD78.25 (PB7), R93.1, X2.A11 (21)
KBD_ACK: DD78.13 (PC4), X2.B10 (20)
LG1: DD67.5 (~RD), DD70.11 (GATE0), DD70.14 (GATE1), DD75.16 (M/~S); also elsewhere on the board
LP0: DD68.4 (2), R49.2, X3.2
LP1: DD69.12 (2), R48.2, X3.3
LP2: DD69.8 (2), R47.2, X3.4
LP3: DD69.4 (2), R46.2, X3.5
LP4: DD69.2, R45.2, X3.6
LP5: DD69.6 (2), R44.2, X3.7
LP6: DD69.10 (2), R43.2, X3.8
LP7: DD68.2, R42.2, X3.9
unnamed: DD12.4 (2), DD70.16 (GATE2)
unnamed: DD12.10 (2), DD70.18 (CLK2)
unnamed: DD12.13 (1), DD70.17 (OUT3)
unnamed: DD67.17 (PC3), R36.2
unnamed: DD67.13 (PC4), DD68.13 (1)
unnamed: DD67.12 (PC5), DD68.11 (1)
unnamed: DD67.11 (PC6), DD68.9 (1)
unnamed: DD67.10 (PC7), DD68.5 (1)
unnamed: DD70.13 (OUT2), DD72.9 (~TXC), DD72.25 (~RXC)
unnamed: CR1.1, DD73.1 (C1+)
unnamed: CR1.2, DD73.3 (C1-)
unnamed: CR2.1, DD73.4 (C2+)
unnamed: CR2.2, DD73.5 (C2-)
unnamed: CR3.2, DD73.2 (V+)
unnamed: CR4.2, DD73.6 (V-)
unnamed: R80.1, S2.1
unnamed: R36.1, VT12.3 (B), VT13.3 (B)
unnamed: R37.2, VT12.1 (E), VT13.1 (E)
P0-PA0: DD79.4 (PA0), X5.B12 (24)
P0-PA1: DD79.3 (PA1), X5.B13 (26)
P0-PA2: DD79.2 (PA2), X5.B14 (28)
P0-PA3: DD79.1 (PA3), X5.A15 (29)
P0-PA4: DD79.40 (PA4), X5.B15 (30)
P0-PA5: DD79.39 (PA5), X5.A14 (27)
P0-PA6: DD79.38 (PA6), X5.A13 (25)
P0-PA7: DD79.37 (PA7), X5.A12 (23)
P0-PB0: DD79.18 (PB0), X5.B5 (10)
P0-PB1: DD79.19 (PB1), X5.B4 (8)
P0-PB2: DD79.20 (PB2), X5.B3 (6)
P0-PB3: DD79.21 (PB3), X5.A3 (5)
P0-PB4: DD79.22 (PB4), X5.A4 (7)
P0-PB5: DD79.23 (PB5), X5.A5 (9)
P0-PB6: DD79.24 (PB6), X5.A6 (11)
P0-PB7: DD79.25 (PB7), X5.A7 (13)
P0-PC0: DD79.14 (PC0), X5.A9 (17)
P0-PC1: DD79.15 (PC1), X5.B8 (16)
P0-PC2: DD79.16 (PC2), X5.B7 (14)
P0-PC3: DD79.17 (PC3), X5.B6 (12)
P0-PC4: DD79.13 (PC4), X5.B10 (20)
P0-PC5: DD79.12 (PC5), X5.A10 (19)
P0-PC6: DD79.11 (PC6), X5.B11 (22)
P0-PC7: DD79.10 (PC7), X5.A11 (21)
P4-PA0: DD78.4 (PA0), X2.A5 (9)
P4-PA1: DD78.3 (PA1), X2.B5 (10)
P4-PA2: DD78.2 (PA2), X2.A4 (7)
P4-PA3: DD78.1 (PA3), X2.B4 (8)
P4-PA4: DD78.40 (PA4), X2.B6 (12)
P4-PA5: DD78.39 (PA5), X2.A6 (11)
P4-PA6: DD78.38 (PA6), X2.B7 (14)
P4-PA7: DD78.37 (PA7), X2.A7 (13)
P4-PC0: DD78.14 (PC0), X2.A10 (19)
P4-PC1: DD78.15 (PC1), X2.B11 (22)
P4-PC2: DD78.16 (PC2), X2.B12 (24)
P4-PC3: DD78.17 (PC3), X2.B13 (26)
P4-PC5: DD78.12 (PC5), X2.A9 (17)
P4-PC6: DD78.11 (PC6), X2.A8 (15)
P4-PC7: DD78.10 (PC7), X2.B8 (16)
READY: DD80.22 (RDSYS); also elsewhere on the board
RESET: DD67.35 (RES), DD72.21 (RESET), DD78.35 (RES), DD79.35 (RES), DD80.37 (RES); also elsewhere on the board
RST0: DD71.4 (2), DD75.18 (IR0)
RST1: DD71.2, DD75.19 (IR1)
RST2: DD72.14 (RXRDY), DD75.20 (IR2)
RST3: DD23.11 (3), DD75.21 (IR3)
RST4: DD70.10 (OUT1), DD75.22 (IR4)
RST5: DD71.8 (2), DD75.23 (IR5)
RST6: DD71.10 (2), DD75.24 (IR6)
RST7: DD71.12 (2), DD75.25 (IR7)
RST_0: DD71.3 (1), R78.1, X2.A15 (29)
RST_1: DD71.1, R82.1, X2.B15 (30)
RST_6: DD71.11 (1), R83.1, XT1.4
RST_7: DD71.13 (1), R84.1, XT1.5
RST_BTN: X2.B9 (18); also elsewhere on the board
RXD: DD72.3 (RXD), DD73.9 (R2OUT), XR2.3
STB-LP: DD68.12 (2), R41.2, X3.1
TAPE1: DD67.14 (PC0); also elsewhere on the board
TAPE2: DD67.15 (PC1); also elsewhere on the board
TAPE3: DD67.16 (PC2); also elsewhere on the board
TAPE4: DD78.20 (PB2); also elsewhere on the board
TAPE5: DD78.21 (PB3); also elsewhere on the board
TIM_EN: DD12.3 (1), R50.2, XT1.2
TIM_IN: DD12.11 (1), XT1.3
TIM_OUT: DD12.12 (2), XT1.1
TXD: DD72.19 (TXD), DD73.10 (T2IN), XR2.4
USER1: DD68.10 (2), R40.2, XU1.4
USER2: DD68.8 (2), R39.2, XU1.3
USER3: DD68.6 (2), R38.2, XU1.5
U_RST: DD71.9 (1), R61.1
VCC: CR3.1, CR5.1, DD67.26 (VCC), DD68.14 (VCC), DD69.14 (VCC), DD70.24 (VCC), DD71.14 (VCC), DD72.26 (VCC), DD73.16 (VCC), DD75.28 (VCC), DD78.26 (VCC), DD79.26 (VCC), DD80.28 (VCC), R38.1, R39.1, R40.1, R41.1, R42.1, R43.1, R44.1, R45.1, R46.1, R47.1, R48.1, R49.1, R50.1, R61.2, R78.2, R79.2, R80.2, R81.2, R82.2, R83.2, R84.2, R91.2, R92.2, R93.2, VT12.2 (C), X2.A2 (3), X2.A3 (5), X2.B3 (6), X4.A8 (15), X4.A16 (31), X4.B16 (32), X5.A8 (15), XR2.2, XU1.1; also elsewhere on the board
VSU: DD67.25 (PB7); also elsewhere on the board
iDSR: DD73.13 (R1IN), XR1.6
iRXD: DD73.8 (R2IN), XR1.2
oDTR: DD73.14 (T1OUT), XR1.4
oTXD: DD73.7 (T2OUT), XR1.3
~CS00: DD79.6 (~CS); also elsewhere on the board
~CS20: DD80.6 (~CS); also elsewhere on the board
~CS40: DD78.6 (~CS); also elsewhere on the board
~CS60: DD70.21 (~CS); also elsewhere on the board
~CS80: DD75.1 (~CS); also elsewhere on the board
~CSA0: DD72.11 (~CS); also elsewhere on the board
~CSE0: DD67.6 (~CS); also elsewhere on the board
~DSR: DD72.22 (DSR), DD73.12 (R1OUT), XR2.6
~DTR: DD72.24 (~DTR), DD73.11 (T1IN), XR2.5
~INTA: DD75.26 (~INTA); also elsewhere on the board
~IOR: DD70.22 (~RD), DD72.13 (~RD), DD75.3 (~RD), DD78.5 (~RD), DD79.5 (~RD), DD80.5 (~RD); also elsewhere on the board
~IOW: DD67.36 (~WR), DD70.23 (~WR), DD72.10 (~WR), DD75.2 (~WR), DD78.36 (~WR), DD79.36 (~WR), DD80.38 (~WR); also elsewhere on the board

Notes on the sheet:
Для внешних устройств пользователя
Порты A и С, B5-7 - Клавиатура
Для устройств пользователя или FDC

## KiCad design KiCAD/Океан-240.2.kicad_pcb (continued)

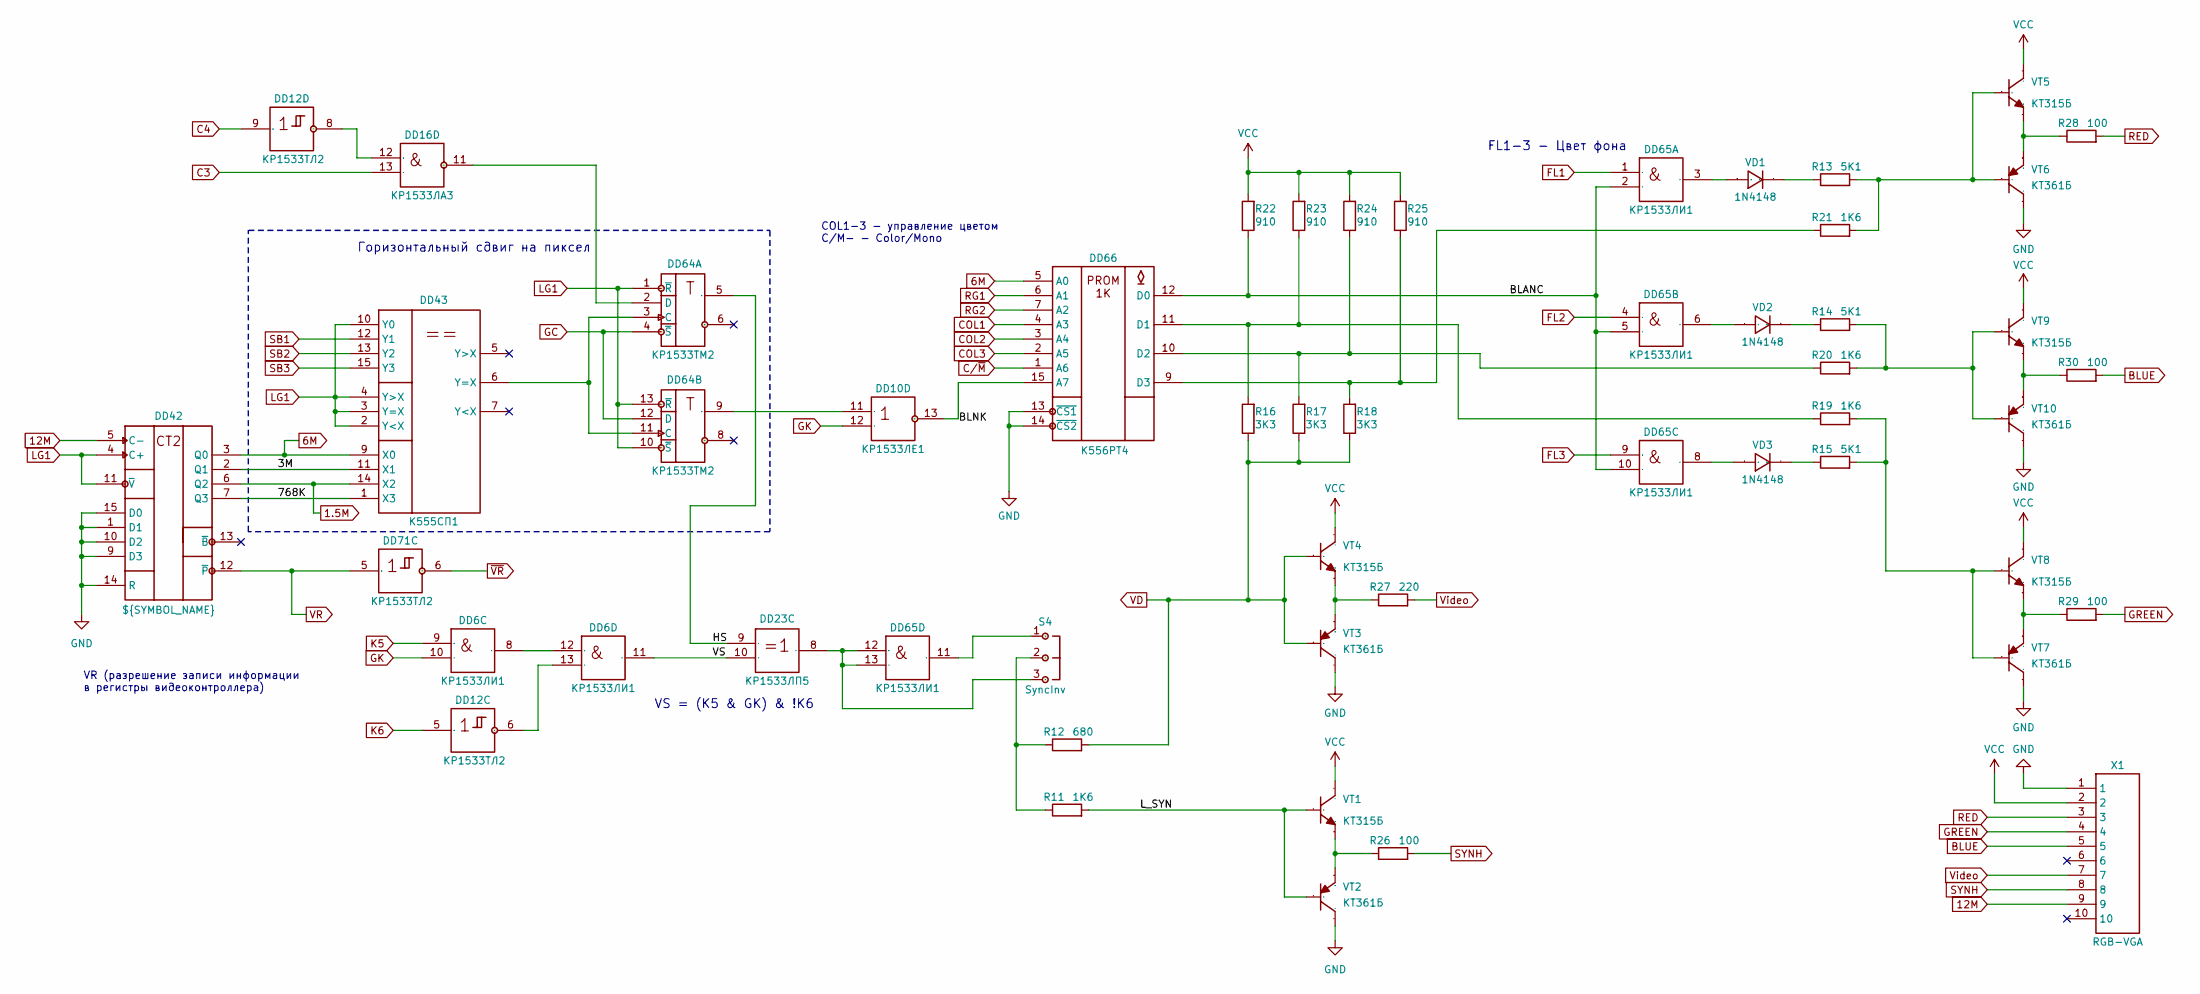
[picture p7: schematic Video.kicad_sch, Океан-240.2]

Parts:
DD6, DD65: КР1533ЛИ1; DIP-14_W7.62mm
DD10: КР1533ЛЕ1; DIP-14_W7.62mm
DD12, DD71: КР1533ТЛ2; DIP-14_W7.62mm
DD16: КР1533ЛА3; DIP-14_W7.62mm
DD23: КР1533ЛП5; DIP-14_W7.62mm
DD42: ${SYMBOL_NAME}; DIP-16_W7.62mm
DD43: К555СП1; DIP-16_W7.62mm
DD64: КР1533ТМ2; DIP-14_W7.62mm
DD66: К556РТ4; DIP-16_W7.62mm
R11, R19, R20, R21: 1K6; RES_0.125W_P7.62
R12: 680; RES_0.125W_P7.62
R13, R14, R15: 5K1; RES_0.125W_P7.62
R16, R17, R18: 3K3; RES_0.125W_P7.62
R22, R23, R24, R25: 910; RES_0.125W_P7.62
R26, R28, R29, R30: 100; RES_0.125W_P7.62
R27: 220; RES_0.125W_P7.62
S4: SyncInv; HDR-3P-M-P2.54
VD1, VD2, VD3: 1N4148; DO-35_TH_P7.62
VT1, VT4, VT5, VT8, VT9: КТ315Б; KT315_STD
VT2, VT3, VT6, VT7, VT10: КТ361Б; KT315_STD
X1: RGB-VGA; HDR-10P-M-P2.54

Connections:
1.5M: DD42.6 (Q2), DD43.14 (X2); also elsewhere on the board
6M: DD42.3 (Q0), DD43.9 (X0), DD66.5 (A0); also elsewhere on the board
12M: DD42.5 (C-), X1.9; also elsewhere on the board
/Океан-240.2 - Видео/3M: DD42.2 (Q1), DD43.11 (X1)
/Океан-240.2 - Видео/768K: DD42.7 (Q3), DD43.1 (X3)
/Океан-240.2 - Видео/BLANC: DD65.2, DD65.5 (2), DD65.10 (2), DD66.12 (D0), R22.1
/Океан-240.2 - Видео/BLNK: DD10.13 (3), DD66.15 (A7)
/Океан-240.2 - Видео/HS: DD23.9 (1), DD64.5 (Q)
/Океан-240.2 - Видео/L_SYN: R11.2, VT1.3 (B), VT2.3 (B)
/Океан-240.2 - Видео/VS: DD6.11 (3), DD23.10 (2)
BLUE: R30.2, X1.5
C3: DD16.13 (2); also elsewhere on the board
C4: DD12.9 (1); also elsewhere on the board
COL1: DD66.4 (A3); also elsewhere on the board
COL2: DD66.3 (A4); also elsewhere on the board
COL3: DD66.2 (A5); also elsewhere on the board
C/~M: DD66.1 (A6); also elsewhere on the board
FL1: DD65.1; also elsewhere on the board
FL2: DD65.4 (1); also elsewhere on the board
FL3: DD65.9 (1); also elsewhere on the board
GC: DD64.4 (~S), DD64.12 (D); also elsewhere on the board
GK: DD6.10 (2), DD10.12 (2); also elsewhere on the board
GND: DD42.1 (D1), DD42.8 (GND), DD42.9 (D3), DD42.10 (D2), DD42.14 (R), DD42.15 (D0), DD43.8 (GND), DD64.7 (GND), DD65.7 (GND), DD66.8 (GND), DD66.13 (~CS1), DD66.14 (~CS2), VT2.2 (C), VT3.2 (C), VT6.2 (C), VT7.2 (C), VT10.2 (C), X1.1; also elsewhere on the board
GREEN: R29.2, X1.4
K5: DD6.9 (1); also elsewhere on the board
K6: DD12.5 (1); also elsewhere on the board
LG1: DD42.4 (C+), DD42.11 (~V), DD43.2 (Y<X), DD43.3 (Y=X), DD43.4 (Y>X), DD43.10 (Y0), DD64.1 (~R), DD64.10 (~S), DD64.13 (~R); also elsewhere on the board
unnamed: DD6.8 (3), DD6.12 (1)
unnamed: DD10.11 (1), DD64.9 (Q)
unnamed: DD6.13 (2), DD12.6 (2)
unnamed: DD12.8 (2), DD16.12 (1)
unnamed: DD16.11 (3), DD64.2 (D)
unnamed: DD23.8 (3), DD65.12 (1), DD65.13 (2), S4.3
unnamed: DD43.6 (Y=X), DD64.3 (С), DD64.11 (С)
unnamed: DD65.6 (3), VD2.1 (A)
unnamed: DD65.8 (3), VD3.1 (A)
unnamed: DD65.11 (3), S4.1
unnamed: DD66.11 (D1), R16.2, R19.1, R23.1
unnamed: DD66.10 (D2), R17.2, R20.1, R24.1
unnamed: DD66.9 (D3), R18.2, R21.1, R25.1
unnamed: R11.1, R12.1, S4.2
unnamed: DD65.3, VD1.1 (A)
unnamed: R13.1, VD1.2 (K)
unnamed: R14.1, VD2.2 (K)
unnamed: R15.1, VD3.2 (K)
unnamed: R26.1, VT1.1 (E), VT2.1 (E)
unnamed: R27.1, VT3.1 (E), VT4.1 (E)
unnamed: R13.2, R21.2, VT5.3 (B), VT6.3 (B)
unnamed: R28.1, VT5.1 (E), VT6.1 (E)
unnamed: R15.2, R19.2, VT7.3 (B), VT8.3 (B)
unnamed: R29.1, VT7.1 (E), VT8.1 (E)
unnamed: R14.2, R20.2, VT9.3 (B), VT10.3 (B)
unnamed: R30.1, VT9.1 (E), VT10.1 (E)
RED: R28.2, X1.3
RG1: DD66.6 (A1); also elsewhere on the board
RG2: DD66.7 (A2); also elsewhere on the board
SB1: DD43.12 (Y1); also elsewhere on the board
SB2: DD43.13 (Y2); also elsewhere on the board
SB3: DD43.15 (Y3); also elsewhere on the board
SYNH: R26.2, X1.8
VCC: DD42.16 (VCC), DD43.16 (VCC), DD64.14 (VCC), DD65.14 (VCC), DD66.16 (VCC), R22.2, R23.2, R24.2, R25.2, VT1.2 (C), VT4.2 (C), VT5.2 (C), VT8.2 (C), VT9.2 (C), X1.2; also elsewhere on the board
VD: R12.2, R16.1, R17.1, R18.1, VT3.3 (B), VT4.3 (B)
VR: DD42.12 (~P), DD71.5 (1); also elsewhere on the board
Video: R27.2, X1.7
~VR: DD71.6 (2); also elsewhere on the board

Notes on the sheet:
FL1-3 - Цвет фона
VR (разрешение записи информации в регистры видеоконтроллера)
COL1-3 - управление цветом C/M- - Color/Mono
VS = (K5 & GK) & !K6
Горизонтальный сдвиг на пиксел

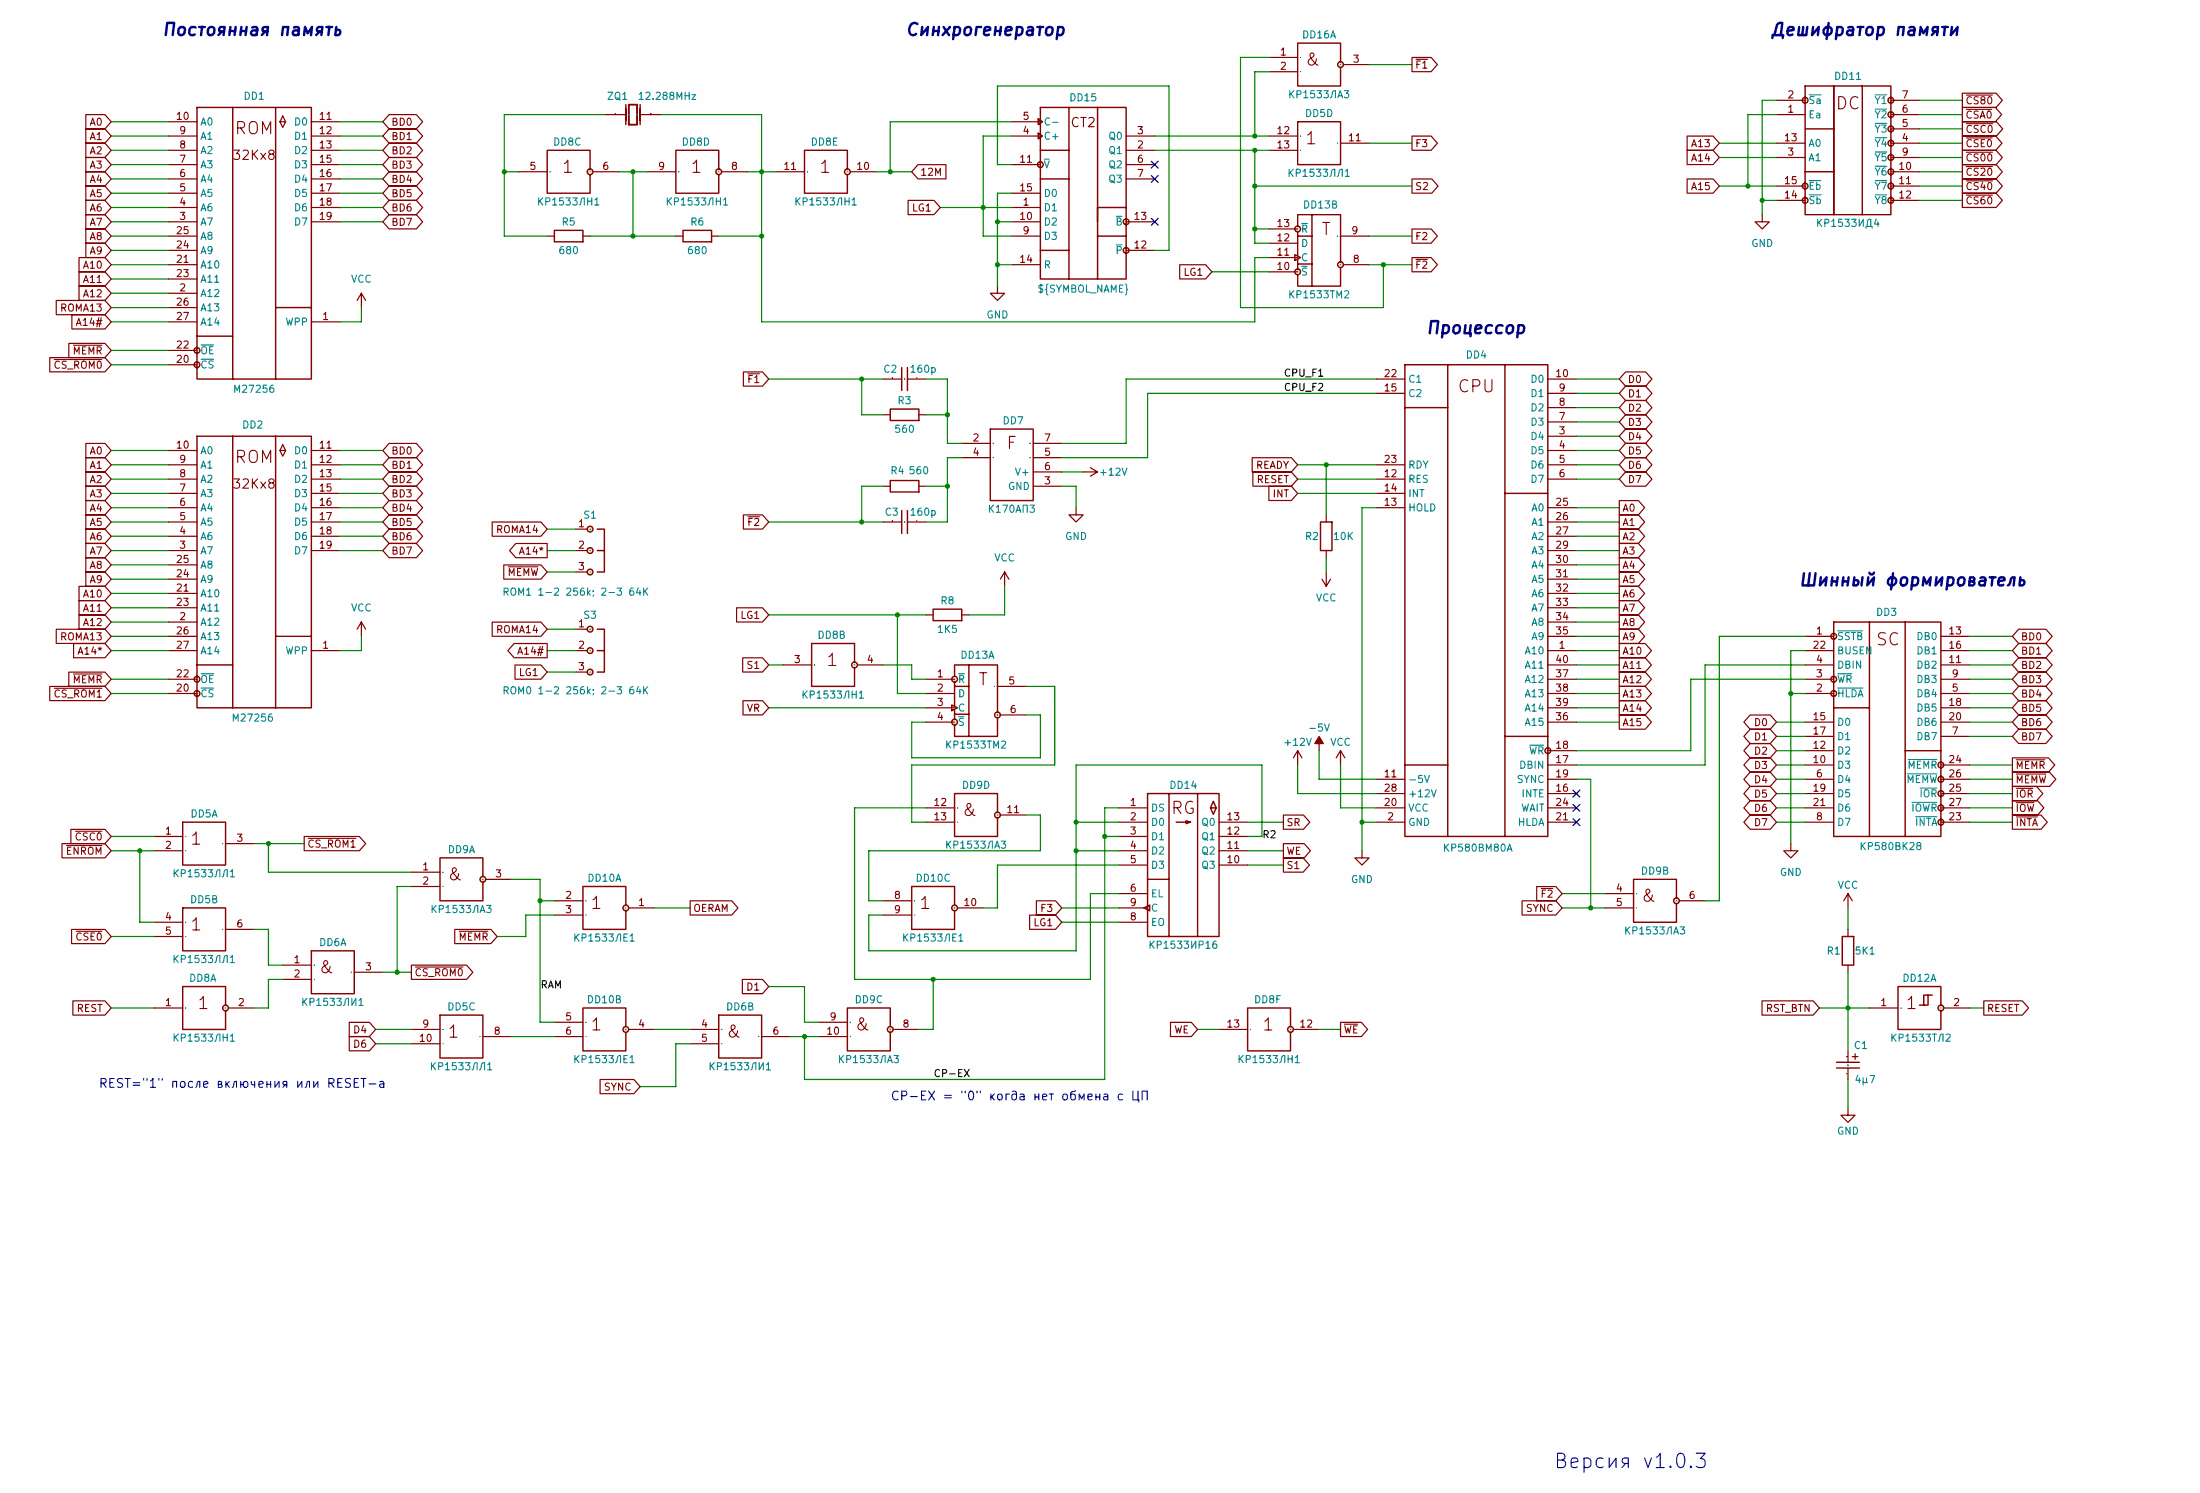
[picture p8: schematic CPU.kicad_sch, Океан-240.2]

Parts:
C1: 4μ7; CAP_P-TH-5x11-P2.54
C2, C3: 160p; CAP-TH_L7.62
DD1, DD2: M27256; DIP-28_W15.24mm_Socket
DD3: КР580ВК28; DIP-28_W15.24mm
DD4: КР580ВМ80А; DIP-40_W15.24mm_Socket
DD5: КР1533ЛЛ1; DIP-14_W7.62mm
DD6: КР1533ЛИ1; DIP-14_W7.62mm
DD7: К170АП3; DIP-8_W7.62mm
DD8: КР1533ЛН1; DIP-14_W7.62mm
DD9, DD16: КР1533ЛА3; DIP-14_W7.62mm
DD10: КР1533ЛЕ1; DIP-14_W7.62mm
DD11: КР1533ИД4; DIP-16_W7.62mm
DD12: КР1533ТЛ2; DIP-14_W7.62mm
DD13: КР1533ТМ2; DIP-14_W7.62mm
DD14: КР1533ИР16; DIP-14_W7.62mm
DD15: ${SYMBOL_NAME}; DIP-16_W7.62mm
R1: 5K1; RES_0.125W_P7.62
R2: 10K; RES_0.125W_P7.62
R3, R4: 560; RES_0.125W_P7.62
R5, R6: 680; RES_0.125W_P7.62
R8: 1K5; RES_0.125W_P7.62
S1: ROM1 1-2 256k; 2-3 64K; HDR-3P-M-P2.54
S3: ROM0 1-2 256k; 2-3 64K; HDR-3P-M-P2.54
ZQ1: 12.288MHz; Crystal_HC49-U_Vertical

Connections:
12M: DD8.10 (2), DD15.5 (C-); also elsewhere on the board
+12V: DD4.28 (+12V), DD7.6 (V+); also elsewhere on the board
-5V: DD4.11 (-5V); also elsewhere on the board
/Океан-240.2 - ЦПУ, ПЗУ, синхронизация/CP-EX: DD6.6 (3), DD9.10 (2), DD14.1 (DS), DD14.3 (D1)
/Океан-240.2 - ЦПУ, ПЗУ, синхронизация/CPU_F1: DD4.22 (С1), DD7.7 (O1)
/Океан-240.2 - ЦПУ, ПЗУ, синхронизация/CPU_F2: DD4.15 (С2), DD7.5 (O2)
/Океан-240.2 - ЦПУ, ПЗУ, синхронизация/R2: DD10.9 (2), DD14.2 (D0), DD14.4 (D2), DD14.12 (Q1)
/Океан-240.2 - ЦПУ, ПЗУ, синхронизация/RAM: DD9.3, DD10.2 (1), DD10.5 (1)
A0: DD1.10 (A0), DD2.10 (A0), DD4.25 (A0); also elsewhere on the board
A1: DD1.9 (A1), DD2.9 (A1), DD4.26 (A1); also elsewhere on the board
A2: DD1.8 (A2), DD2.8 (A2), DD4.27 (A2); also elsewhere on the board
A3: DD1.7 (A3), DD2.7 (A3), DD4.29 (A3); also elsewhere on the board
A4: DD1.6 (A4), DD2.6 (A4), DD4.30 (A4); also elsewhere on the board
A5: DD1.5 (A5), DD2.5 (A5), DD4.31 (A5); also elsewhere on the board
A6: DD1.4 (A6), DD2.4 (A6), DD4.32 (A6); also elsewhere on the board
A7: DD1.3 (A7), DD2.3 (A7), DD4.33 (A7); also elsewhere on the board
A8: DD1.25 (A8), DD2.25 (A8), DD4.34 (A8); also elsewhere on the board
A9: DD1.24 (A9), DD2.24 (A9), DD4.35 (A9); also elsewhere on the board
A10: DD1.21 (A10), DD2.21 (A10), DD4.1 (A10); also elsewhere on the board
A11: DD1.23 (A11), DD2.23 (A11), DD4.40 (A11); also elsewhere on the board
A12: DD1.2 (A12), DD2.2 (A12), DD4.37 (A12); also elsewhere on the board
A13: DD4.38 (A13), DD11.13 (A0); also elsewhere on the board
A14: DD4.39 (A14), DD11.3 (A1); also elsewhere on the board
A14#: DD1.27 (A14), S3.2
A14*: DD2.27 (A14), S1.2
A15: DD4.36 (A15), DD11.1 (Ea), DD11.15 (~Eb); also elsewhere on the board
BD0: DD1.11 (D0), DD2.11 (D0), DD3.13 (DB0); also elsewhere on the board
BD1: DD1.12 (D1), DD2.12 (D1), DD3.16 (DB1); also elsewhere on the board
BD2: DD1.13 (D2), DD2.13 (D2), DD3.11 (DB2); also elsewhere on the board
BD3: DD1.15 (D3), DD2.15 (D3), DD3.9 (DB3); also elsewhere on the board
BD4: DD1.16 (D4), DD2.16 (D4), DD3.5 (DB4); also elsewhere on the board
BD5: DD1.17 (D5), DD2.17 (D5), DD3.18 (DB5); also elsewhere on the board
BD6: DD1.18 (D6), DD2.18 (D6), DD3.20 (DB6); also elsewhere on the board
BD7: DD1.19 (D7), DD2.19 (D7), DD3.7 (DB7); also elsewhere on the board
D0: DD3.15 (D0), DD4.10 (D0); also elsewhere on the board
D1: DD3.17 (D1), DD4.9 (D1), DD9.9 (1); also elsewhere on the board
D2: DD3.12 (D2), DD4.8 (D2); also elsewhere on the board
D3: DD3.10 (D3), DD4.7 (D3); also elsewhere on the board
D4: DD3.6 (D4), DD4.3 (D4), DD5.9 (1); also elsewhere on the board
D5: DD3.19 (D5), DD4.4 (D5); also elsewhere on the board
D6: DD3.21 (D6), DD4.5 (D6), DD5.10 (2); also elsewhere on the board
D7: DD3.8 (D7), DD4.6 (D7); also elsewhere on the board
F2: DD13.9 (Q); also elsewhere on the board
F3: DD5.11 (3), DD14.9 (C); also elsewhere on the board
GND: C1.2, DD1.14 (GND), DD2.14 (GND), DD3.2 (~HLDA), DD3.14 (GND), DD3.22 (BUSEN), DD4.2 (GND), DD4.13 (HOLD), DD5.7 (GND), DD6.7 (GND), DD7.3 (GND), DD8.7 (GND), DD9.7 (GND), DD10.7 (GND), DD11.2 (~Sa), DD11.8 (GND), DD11.14 (~Sb), DD12.7 (GND), DD13.7 (GND), DD14.7 (GND), DD15.8 (GND), DD15.10 (D2), DD15.14 (R), DD15.15 (D0), DD16.7 (GND); also elsewhere on the board
INT: DD4.14 (INT); also elsewhere on the board
LG1: DD13.2 (D), DD13.10 (~S), DD14.8 (EO), DD15.1 (D1), DD15.4 (C+), DD15.9 (D3), R8.1, S3.3; also elsewhere on the board
unnamed: DD3.4 (DBIN), DD4.17 (DBIN)
unnamed: DD3.1 (~SSTB), DD9.6 (3)
unnamed: DD3.3 (~WR), DD4.18 (~WR)
unnamed: DD5.6 (3), DD6.1
unnamed: DD6.2, DD8.2
unnamed: C2.2, DD7.2 (I1), R3.2
unnamed: C3.2, DD7.4 (I2), R4.2
unnamed: DD8.5 (1), R5.1, ZQ1.2 (OSC2)
unnamed: DD8.6 (2), DD8.9 (1), R5.2, R6.1
unnamed: DD5.8 (3), DD10.6 (2)
unnamed: DD6.4 (1), DD10.4 (3)
unnamed: DD9.11 (3), DD10.8 (1)
unnamed: DD10.10 (3), DD14.5 (D3)
unnamed: DD9.13 (2), DD13.5 (Q)
unnamed: DD13.4 (~S), DD13.6 (~Q)
unnamed: DD8.4 (2), DD13.1 (~R)
unnamed: DD8.8 (2), DD8.11 (1), DD13.11 (С), R6.2, ZQ1.1 (OSC1)
unnamed: DD9.8 (3), DD9.12 (1), DD14.6 (EL)
unnamed: DD5.12 (1), DD15.3 (Q0), DD16.2
unnamed: DD15.11 (~V), DD15.12 (~P)
OERAM: DD10.1 (3); also elsewhere on the board
READY: DD4.23 (RDY), R2.2; also elsewhere on the board
RESET: DD4.12 (RES), DD12.2; also elsewhere on the board
REST: DD8.1; also elsewhere on the board
ROMA13: DD1.26 (A13), DD2.26 (A13); also elsewhere on the board
ROMA14: S1.1, S3.1; also elsewhere on the board
RST_BTN: C1.1, DD12.1, R1.1; also elsewhere on the board
S1: DD8.3 (1), DD14.10 (Q3); also elsewhere on the board
S2: DD5.13 (2), DD13.12 (D), DD13.13 (~R), DD15.2 (Q1); also elsewhere on the board
SR: DD14.13 (Q0); also elsewhere on the board
SYNC: DD4.19 (SYNC), DD6.5 (2), DD9.5 (2)
VCC: DD1.1 (WPP), DD1.28 (VCC), DD2.1 (WPP), DD2.28 (VCC), DD3.28 (VCC), DD4.20 (VCC), DD5.14 (VCC), DD6.14 (VCC), DD8.14 (VCC), DD9.14 (VCC), DD10.14 (VCC), DD11.16 (VCC), DD12.14 (VCC), DD13.14 (VCC), DD14.14 (VCC), DD15.16 (VCC), DD16.14 (VCC), R1.2, R2.1, R8.2; also elsewhere on the board
VR: DD13.3 (С); also elsewhere on the board
WE: DD8.13 (1), DD14.11 (Q2)
~CS00: DD11.9 (~Y5); also elsewhere on the board
~CS20: DD11.10 (~Y6); also elsewhere on the board
~CS40: DD11.11 (~Y7); also elsewhere on the board
~CS60: DD11.12 (~Y8); also elsewhere on the board
~CS80: DD11.7 (~Y1); also elsewhere on the board
~CSA0: DD11.6 (~Y2); also elsewhere on the board
~CSC0: DD5.1, DD11.5 (~Y3); also elsewhere on the board
~CSE0: DD5.5 (2), DD11.4 (~Y4); also elsewhere on the board
~CS_ROM0: DD1.20 (~CS), DD6.3, DD9.2
~CS_ROM1: DD2.20 (~CS), DD5.3, DD9.1
~ENROM: DD5.2, DD5.4 (1); also elsewhere on the board
~F1: C2.1, DD16.3, R3.1
~F2: C3.1, DD9.4 (1), DD13.8 (~Q), DD16.1, R4.1
~INTA: DD3.23 (~INTA); also elsewhere on the board
~IOR: DD3.25 (~IOR); also elsewhere on the board
~IOW: DD3.27 (~IOWR); also elsewhere on the board
~MEMR: DD1.22 (~OE), DD2.22 (~OE), DD3.24 (~MEMR), DD10.3 (2)
~MEMW: DD3.26 (~MEMW), S1.3
~WE: DD8.12 (3); also elsewhere on the board

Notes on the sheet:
REST="1" после включения или RESET-а
Версия ${REVISION}
Постоянная память
CP-EX = "0" когда нет обмена с ЦП
Дешифратор памяти
Синхрогенератор
Процессор
Шинный формирователь

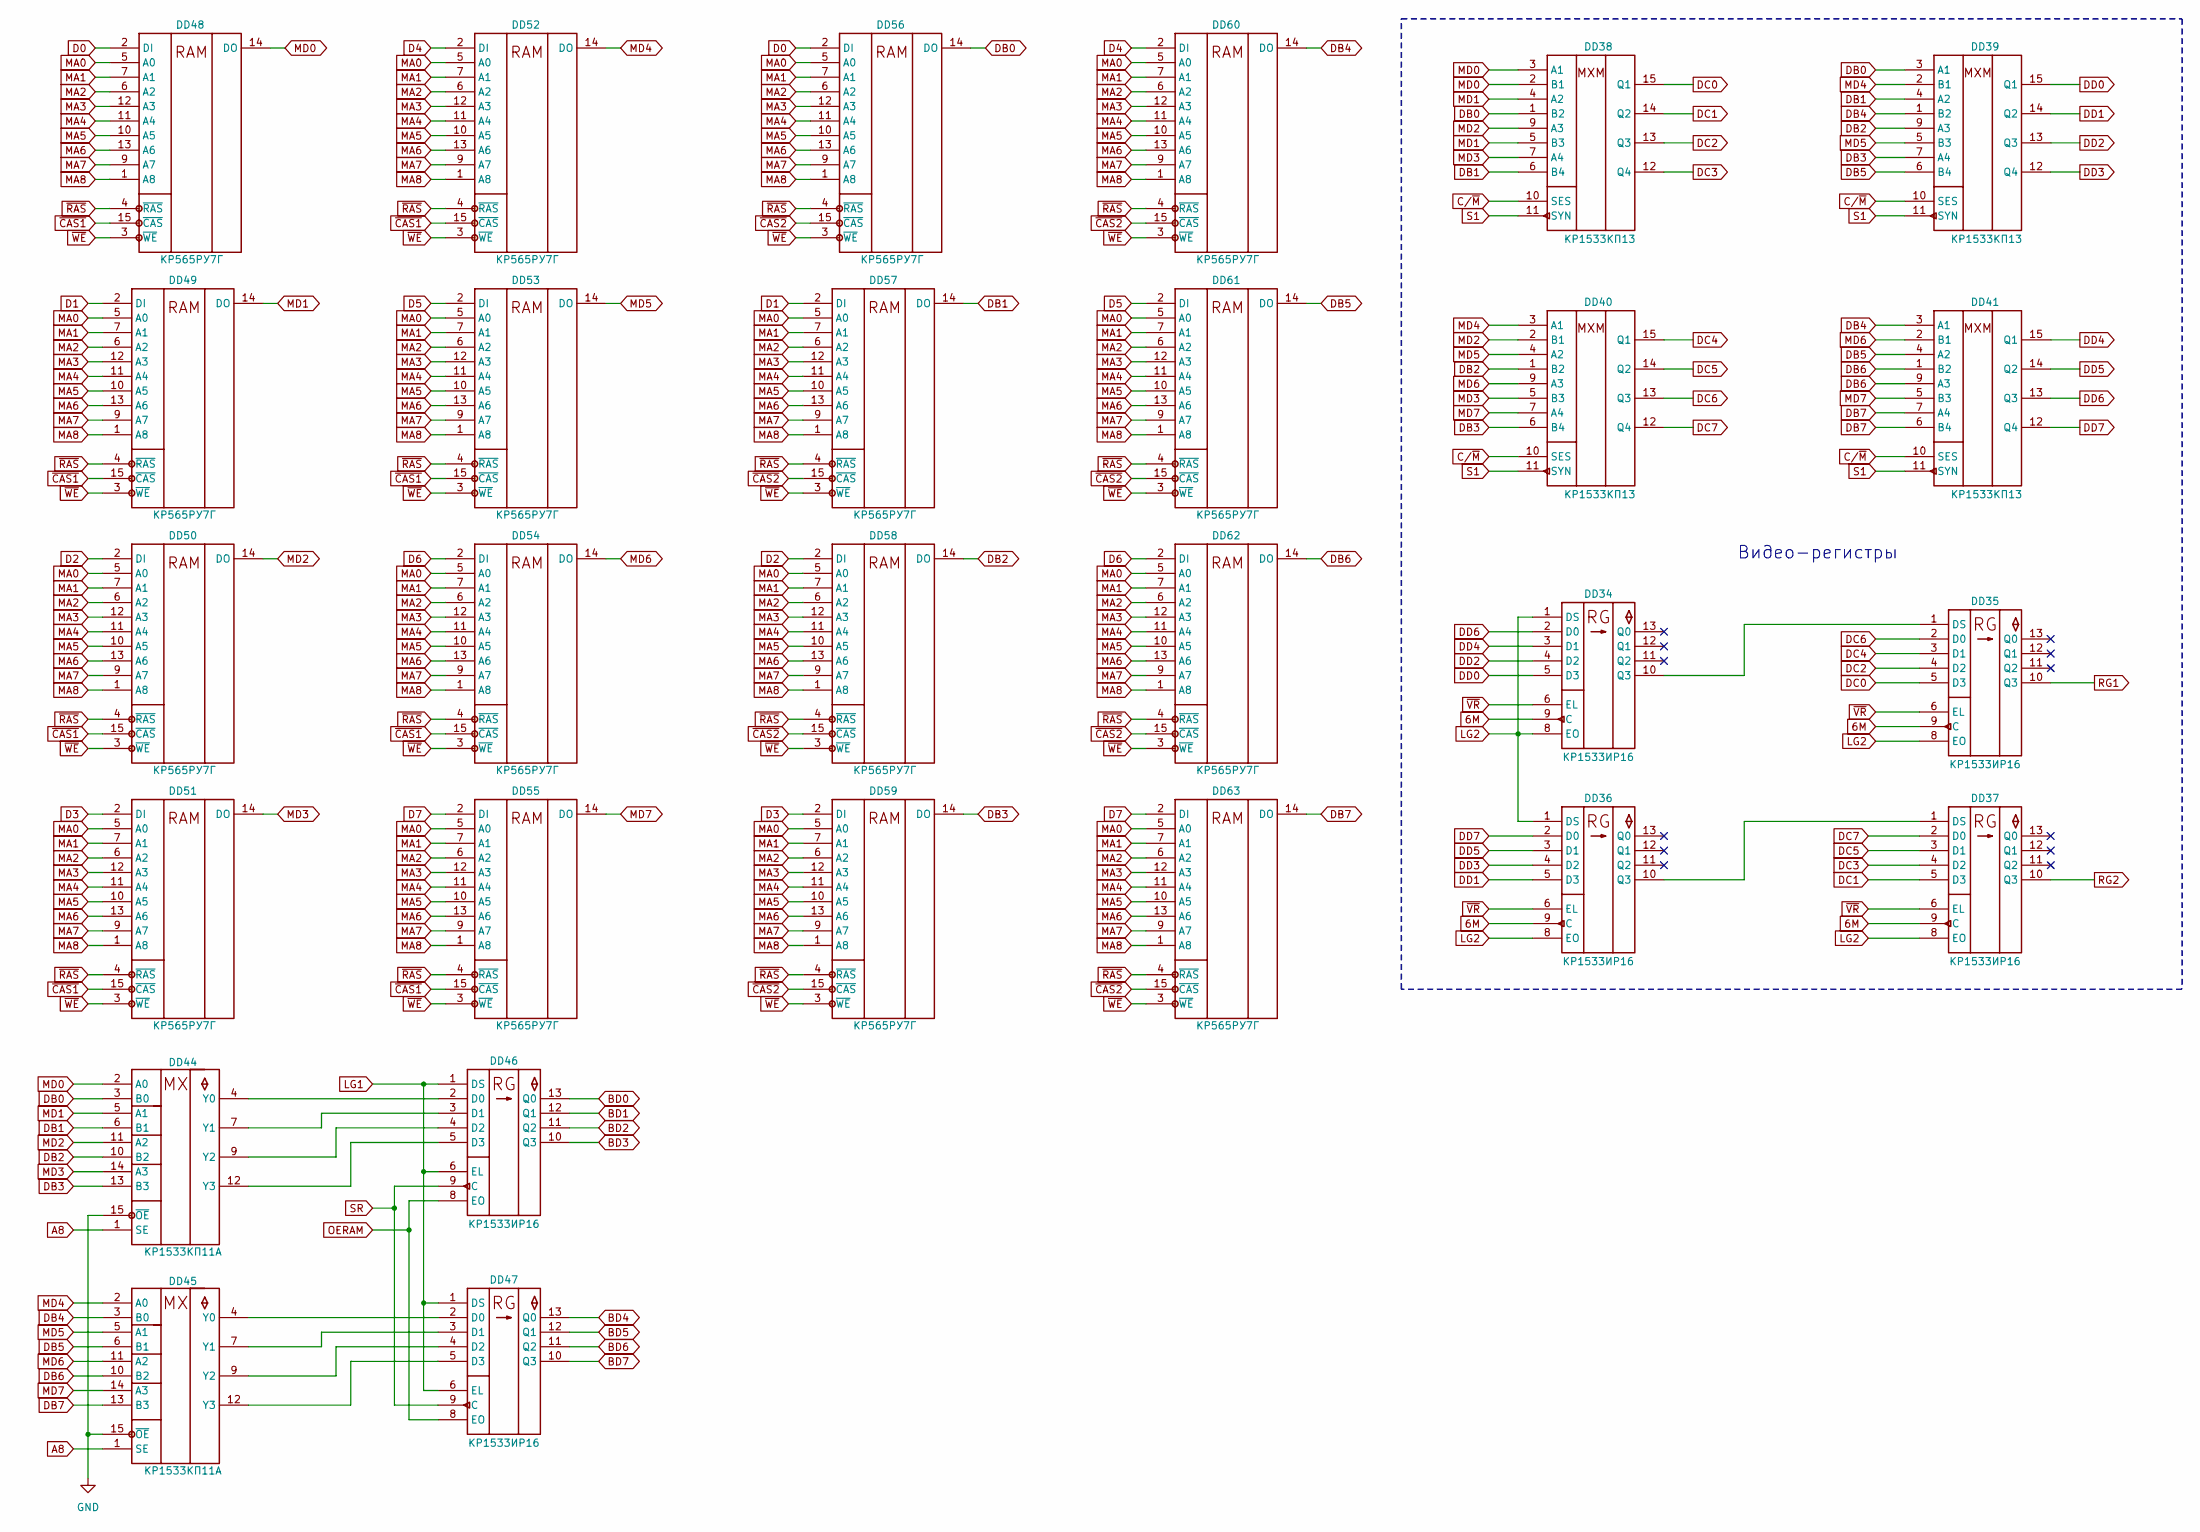
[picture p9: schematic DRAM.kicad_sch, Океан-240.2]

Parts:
DD34, DD35, DD36, DD37, DD46, DD47: КР1533ИР16; DIP-14_W7.62mm
DD38, DD39, DD40, DD41: КР1533КП13; DIP-16_W7.62mm
DD44, DD45: КР1533КП11A; DIP-16_W7.62mm
DD48, DD49, DD50, DD51, DD52, DD53, DD54, DD55, DD56, DD57, DD58, DD59, DD60, DD61, DD62, DD63: КР565РУ7Г; DIP-16_W7.62mm_Socket

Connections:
6M: DD34.9 (C), DD35.9 (C), DD36.9 (C), DD37.9 (C); also elsewhere on the board
A8: DD44.1 (SE), DD45.1 (SE); also elsewhere on the board
BD0: DD46.13 (Q0); also elsewhere on the board
BD1: DD46.12 (Q1); also elsewhere on the board
BD2: DD46.11 (Q2); also elsewhere on the board
BD3: DD46.10 (Q3); also elsewhere on the board
BD4: DD47.13 (Q0); also elsewhere on the board
BD5: DD47.12 (Q1); also elsewhere on the board
BD6: DD47.11 (Q2); also elsewhere on the board
BD7: DD47.10 (Q3); also elsewhere on the board
C/~M: DD38.10 (SES), DD39.10 (SES), DD40.10 (SES), DD41.10 (SES); also elsewhere on the board
D0: DD48.2 (DI), DD56.2 (DI); also elsewhere on the board
D1: DD49.2 (DI), DD57.2 (DI); also elsewhere on the board
D2: DD50.2 (DI), DD58.2 (DI); also elsewhere on the board
D3: DD51.2 (DI), DD59.2 (DI); also elsewhere on the board
D4: DD52.2 (DI), DD60.2 (DI); also elsewhere on the board
D5: DD53.2 (DI), DD61.2 (DI); also elsewhere on the board
D6: DD54.2 (DI), DD62.2 (DI); also elsewhere on the board
D7: DD55.2 (DI), DD63.2 (DI); also elsewhere on the board
DB0: DD38.1 (B2), DD39.3 (A1), DD44.3 (B0), DD56.14 (DO)
DB1: DD38.6 (B4), DD39.4 (A2), DD44.6 (B1), DD57.14 (DO)
DB2: DD39.9 (A3), DD40.1 (B2), DD44.10 (B2), DD58.14 (DO)
DB3: DD39.7 (A4), DD40.6 (B4), DD44.13 (B3), DD59.14 (DO)
DB4: DD39.1 (B2), DD41.3 (A1), DD45.3 (B0), DD60.14 (DO)
DB5: DD39.6 (B4), DD41.4 (A2), DD45.6 (B1), DD61.14 (DO)
DB6: DD41.1 (B2), DD41.9 (A3), DD45.10 (B2), DD62.14 (DO)
DB7: DD41.6 (B4), DD41.7 (A4), DD45.13 (B3), DD63.14 (DO)
DC0: DD35.5 (D3), DD38.15 (Q1)
DC1: DD37.5 (D3), DD38.14 (Q2)
DC2: DD35.4 (D2), DD38.13 (Q3)
DC3: DD37.4 (D2), DD38.12 (Q4)
DC4: DD35.3 (D1), DD40.15 (Q1)
DC5: DD37.3 (D1), DD40.14 (Q2)
DC6: DD35.2 (D0), DD40.13 (Q3)
DC7: DD37.2 (D0), DD40.12 (Q4)
DD0: DD34.5 (D3), DD39.15 (Q1)
DD1: DD36.5 (D3), DD39.14 (Q2)
DD2: DD34.4 (D2), DD39.13 (Q3)
DD3: DD36.4 (D2), DD39.12 (Q4)
DD4: DD34.3 (D1), DD41.15 (Q1)
DD5: DD36.3 (D1), DD41.14 (Q2)
DD6: DD34.2 (D0), DD41.13 (Q3)
DD7: DD36.2 (D0), DD41.12 (Q4)
GND: DD34.7 (GND), DD35.7 (GND), DD36.7 (GND), DD37.7 (GND), DD38.8 (GND), DD39.8 (GND), DD40.8 (GND), DD41.8 (GND), DD44.8 (GND), DD44.15 (~OE), DD45.8 (GND), DD45.15 (~OE), DD46.7 (GND), DD47.7 (GND), DD48.16 (GND), DD49.16 (GND), DD50.16 (GND), DD51.16 (GND), DD52.16 (GND), DD53.16 (GND), DD54.16 (GND), DD55.16 (GND), DD56.16 (GND), DD57.16 (GND), DD58.16 (GND), DD59.16 (GND), DD60.16 (GND), DD61.16 (GND), DD62.16 (GND), DD63.16 (GND); also elsewhere on the board
LG1: DD46.1 (DS), DD46.6 (EL), DD47.1 (DS), DD47.6 (EL); also elsewhere on the board
LG2: DD34.1 (DS), DD34.8 (EO), DD35.8 (EO), DD36.1 (DS), DD36.8 (EO), DD37.8 (EO); also elsewhere on the board
MA0: DD48.5 (A0), DD49.5 (A0), DD50.5 (A0), DD51.5 (A0), DD52.5 (A0), DD53.5 (A0), DD54.5 (A0), DD55.5 (A0), DD56.5 (A0), DD57.5 (A0), DD58.5 (A0), DD59.5 (A0), DD60.5 (A0), DD61.5 (A0), DD62.5 (A0), DD63.5 (A0); also elsewhere on the board
MA1: DD48.7 (A1), DD49.7 (A1), DD50.7 (A1), DD51.7 (A1), DD52.7 (A1), DD53.7 (A1), DD54.7 (A1), DD55.7 (A1), DD56.7 (A1), DD57.7 (A1), DD58.7 (A1), DD59.7 (A1), DD60.7 (A1), DD61.7 (A1), DD62.7 (A1), DD63.7 (A1); also elsewhere on the board
MA2: DD48.6 (A2), DD49.6 (A2), DD50.6 (A2), DD51.6 (A2), DD52.6 (A2), DD53.6 (A2), DD54.6 (A2), DD55.6 (A2), DD56.6 (A2), DD57.6 (A2), DD58.6 (A2), DD59.6 (A2), DD60.6 (A2), DD61.6 (A2), DD62.6 (A2), DD63.6 (A2); also elsewhere on the board
MA3: DD48.12 (A3), DD49.12 (A3), DD50.12 (A3), DD51.12 (A3), DD52.12 (A3), DD53.12 (A3), DD54.12 (A3), DD55.12 (A3), DD56.12 (A3), DD57.12 (A3), DD58.12 (A3), DD59.12 (A3), DD60.12 (A3), DD61.12 (A3), DD62.12 (A3), DD63.12 (A3); also elsewhere on the board
MA4: DD48.11 (A4), DD49.11 (A4), DD50.11 (A4), DD51.11 (A4), DD52.11 (A4), DD53.11 (A4), DD54.11 (A4), DD55.11 (A4), DD56.11 (A4), DD57.11 (A4), DD58.11 (A4), DD59.11 (A4), DD60.11 (A4), DD61.11 (A4), DD62.11 (A4), DD63.11 (A4); also elsewhere on the board
MA5: DD48.10 (A5), DD49.10 (A5), DD50.10 (A5), DD51.10 (A5), DD52.10 (A5), DD53.10 (A5), DD54.10 (A5), DD55.10 (A5), DD56.10 (A5), DD57.10 (A5), DD58.10 (A5), DD59.10 (A5), DD60.10 (A5), DD61.10 (A5), DD62.10 (A5), DD63.10 (A5); also elsewhere on the board
MA6: DD48.13 (A6), DD49.13 (A6), DD50.13 (A6), DD51.13 (A6), DD52.13 (A6), DD53.13 (A6), DD54.13 (A6), DD55.13 (A6), DD56.13 (A6), DD57.13 (A6), DD58.13 (A6), DD59.13 (A6), DD60.13 (A6), DD61.13 (A6), DD62.13 (A6), DD63.13 (A6); also elsewhere on the board
MA7: DD48.9 (A7), DD49.9 (A7), DD50.9 (A7), DD51.9 (A7), DD52.9 (A7), DD53.9 (A7), DD54.9 (A7), DD55.9 (A7), DD56.9 (A7), DD57.9 (A7), DD58.9 (A7), DD59.9 (A7), DD60.9 (A7), DD61.9 (A7), DD62.9 (A7), DD63.9 (A7); also elsewhere on the board
MA8: DD48.1 (A8), DD49.1 (A8), DD50.1 (A8), DD51.1 (A8), DD52.1 (A8), DD53.1 (A8), DD54.1 (A8), DD55.1 (A8), DD56.1 (A8), DD57.1 (A8), DD58.1 (A8), DD59.1 (A8), DD60.1 (A8), DD61.1 (A8), DD62.1 (A8), DD63.1 (A8); also elsewhere on the board
MD0: DD38.2 (B1), DD38.3 (A1), DD44.2 (A0), DD48.14 (DO)
MD1: DD38.4 (A2), DD38.5 (B3), DD44.5 (A1), DD49.14 (DO)
MD2: DD38.9 (A3), DD40.2 (B1), DD44.11 (A2), DD50.14 (DO)
MD3: DD38.7 (A4), DD40.5 (B3), DD44.14 (A3), DD51.14 (DO)
MD4: DD39.2 (B1), DD40.3 (A1), DD45.2 (A0), DD52.14 (DO)
MD5: DD39.5 (B3), DD40.4 (A2), DD45.5 (A1), DD53.14 (DO)
MD6: DD40.9 (A3), DD41.2 (B1), DD45.11 (A2), DD54.14 (DO)
MD7: DD40.7 (A4), DD41.5 (B3), DD45.14 (A3), DD55.14 (DO)
unnamed: DD34.10 (Q3), DD35.1 (DS)
unnamed: DD36.10 (Q3), DD37.1 (DS)
unnamed: DD44.4 (Y0), DD46.2 (D0)
unnamed: DD44.7 (Y1), DD46.3 (D1)
unnamed: DD44.9 (Y2), DD46.4 (D2)
unnamed: DD44.12 (Y3), DD46.5 (D3)
unnamed: DD45.4 (Y0), DD47.2 (D0)
unnamed: DD45.7 (Y1), DD47.3 (D1)
unnamed: DD45.9 (Y2), DD47.4 (D2)
unnamed: DD45.12 (Y3), DD47.5 (D3)
OERAM: DD46.8 (EO), DD47.8 (EO); also elsewhere on the board
RG1: DD35.10 (Q3); also elsewhere on the board
RG2: DD37.10 (Q3); also elsewhere on the board
S1: DD38.11 (SYN), DD39.11 (SYN), DD40.11 (SYN), DD41.11 (SYN); also elsewhere on the board
SR: DD46.9 (C), DD47.9 (C); also elsewhere on the board
VCC: DD34.14 (VCC), DD35.14 (VCC), DD36.14 (VCC), DD37.14 (VCC), DD38.16 (VCC), DD39.16 (VCC), DD40.16 (VCC), DD41.16 (VCC), DD44.16 (VCC), DD45.16 (VCC), DD46.14 (VCC), DD47.14 (VCC), DD48.8 (VCC), DD49.8 (VCC), DD50.8 (VCC), DD51.8 (VCC), DD52.8 (VCC), DD53.8 (VCC), DD54.8 (VCC), DD55.8 (VCC), DD56.8 (VCC), DD57.8 (VCC), DD58.8 (VCC), DD59.8 (VCC), DD60.8 (VCC), DD61.8 (VCC), DD62.8 (VCC), DD63.8 (VCC); also elsewhere on the board
~CAS1: DD48.15 (~CAS), DD49.15 (~CAS), DD50.15 (~CAS), DD51.15 (~CAS), DD52.15 (~CAS), DD53.15 (~CAS), DD54.15 (~CAS), DD55.15 (~CAS); also elsewhere on the board
~CAS2: DD56.15 (~CAS), DD57.15 (~CAS), DD58.15 (~CAS), DD59.15 (~CAS), DD60.15 (~CAS), DD61.15 (~CAS), DD62.15 (~CAS), DD63.15 (~CAS); also elsewhere on the board
~RAS: DD48.4 (~RAS), DD49.4 (~RAS), DD50.4 (~RAS), DD51.4 (~RAS), DD52.4 (~RAS), DD53.4 (~RAS), DD54.4 (~RAS), DD55.4 (~RAS), DD56.4 (~RAS), DD57.4 (~RAS), DD58.4 (~RAS), DD59.4 (~RAS), DD60.4 (~RAS), DD61.4 (~RAS), DD62.4 (~RAS), DD63.4 (~RAS); also elsewhere on the board
~VR: DD34.6 (EL), DD35.6 (EL), DD36.6 (EL), DD37.6 (EL); also elsewhere on the board
~WE: DD48.3 (~WE), DD49.3 (~WE), DD50.3 (~WE), DD51.3 (~WE), DD52.3 (~WE), DD53.3 (~WE), DD54.3 (~WE), DD55.3 (~WE), DD56.3 (~WE), DD57.3 (~WE), DD58.3 (~WE), DD59.3 (~WE), DD60.3 (~WE), DD61.3 (~WE), DD62.3 (~WE), DD63.3 (~WE); also elsewhere on the board

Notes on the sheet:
Видео-регистры

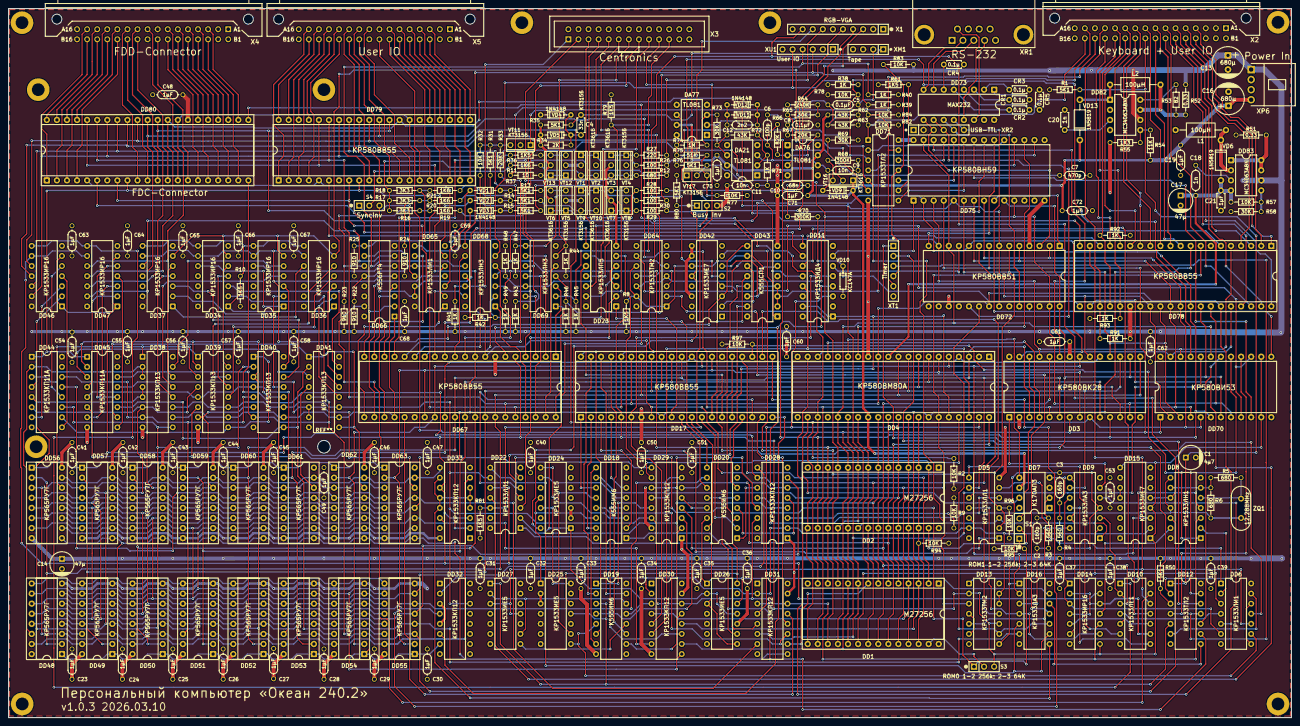
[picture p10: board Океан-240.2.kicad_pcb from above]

Board: 2 copper layers, 323.3 x 178.7 mm, 285 parts (0 on the bottom side), 430 nets.

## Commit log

2025-08-18 BOM added
2025-09-08 Sources for ROMs. Light PCB and Schematics fixes
2025-10-03 Light schematics fixes
2025-12-13 Port to KiCAD v9.0
    [CPU.kicad_sch, DRAM.kicad_sch, Interfaces.kicad_sch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]
2025-12-13 Preview for KiCAD variant
2026-03-10 Fix DD5 and DD22
    [CPU.kicad_sch, Interfaces.kicad_sch, RAM_CTR.kicad_sch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]
2026-03-10 fix ref to gerber
